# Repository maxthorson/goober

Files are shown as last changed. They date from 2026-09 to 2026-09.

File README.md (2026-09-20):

# Goober

Goober is a compact USB-C macro pad project with two connected halves:

- `website/` contains the public Next.js site for presenting the product, linking
  firmware resources, and experimenting with a hosted QMK configurator surface.
- `hardware/` contains the Rev A hardware package: KiCad PCB files, case models,
  QMK firmware, fabrication docs, mockups, validation notes, and release
  deliverables.

The hardware target is a 9-key RP2040-Zero macro pad with MX hot-swap switches,
an OLED display, a volume/mute knob, and individually addressable RGB lighting.
USB hub and charging passthrough are deferred.

## Project Status

Rev A.1 is a checked engineering prototype ready for a first fabrication and fit
test. It has not yet been built or electrically tested on physical hardware.

The hardware package passes schematic ERC, PCB DRC, and KiCad schematic/PCB
parity checks with zero issues. Firmware compiles, and the printable case
components validate as watertight single-body meshes.

## Repository Layout

| Folder | Purpose |
|---|---|
| `website/` | Next.js product site and QMK configurator integration |
| `hardware/case/` | OpenSCAD source and printable STL case files |
| `hardware/docs/` | Design, fabrication, assembly, firmware, and validation guides |
| `hardware/firmware/` | QMK board files, keymap, build script, and UF2 output |
| `hardware/hardware/` | KiCad schematic, PCB, Gerbers, BOM, and part references |
| `hardware/mockups/` | CAD renders, board images, and appearance concepts |
| `hardware/releases/` | Packaged Rev A prototype release archive |
| `hardware/tools/` | Project-owned helper scripts; large external tools are excluded |

## Start Here

For the site:

```bash
cd website
npm install
npm run dev
```

For the hardware:

1. Read `hardware/docs/DESIGN_PLAN.md` and
   `hardware/docs/PARTS_AND_COST.md`.
2. Use `hardware/docs/FABRICATION.md` to order a small PCB batch.
3. Print the fit coupon, then follow `hardware/docs/ASSEMBLY_AND_TEST.md`.
4. Flash the supplied UF2 or rebuild from `hardware/firmware/`.

## Notes

Large installed tools, virtual environments, downloaded toolchains, and upstream
source checkouts are intentionally not committed. License and provenance notes
for the hardware package are in `hardware/NOTICE.md`.

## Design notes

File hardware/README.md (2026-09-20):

# goober

A compact 9-key USB-C macro pad with MX hot-swap switches, an OLED, a volume/mute knob and individually addressable RGB lighting. RP2040-Zero + QMK. **USB hub and charging passthrough are deferred.**

**Rev A.1 is a checked engineering prototype, ready for a first fabrication and fit test. It has not yet been built or electrically tested on hardware.**

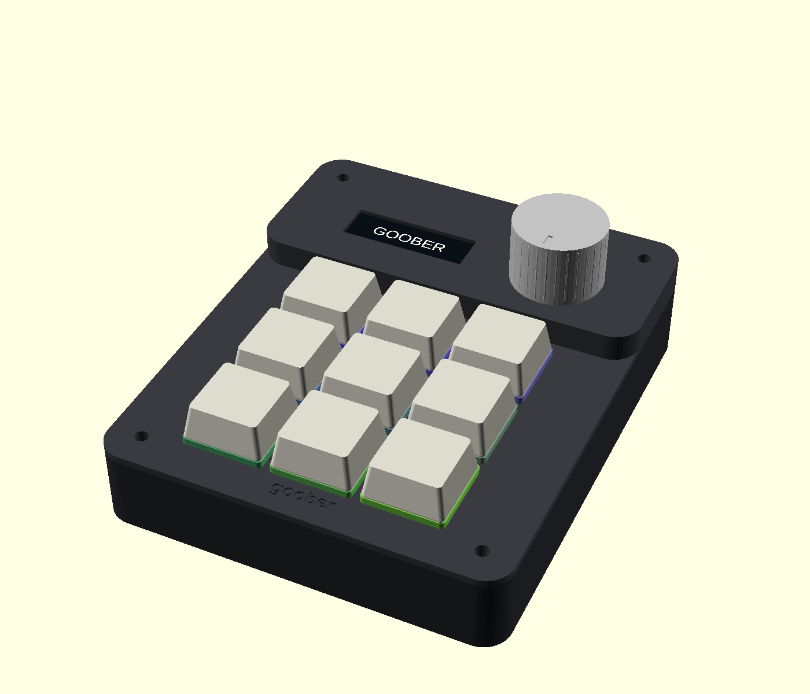
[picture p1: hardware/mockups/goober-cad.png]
Goober mechanical design


## Start here

1. Read [the design plan](docs/DESIGN_PLAN.md) and [parts/cost list](docs/PARTS_AND_COST.md).
2. Use [the fabrication guide](docs/FABRICATION.md) to order a small PCB batch.
3. Print the fit coupon, then follow [assembly and testing](docs/ASSEMBLY_AND_TEST.md).
4. Flash the supplied UF2. [Software and firmware instructions](docs/SOFTWARE_AND_FIRMWARE.md) explain editing and rebuilding.

KiCad, OpenSCAD and the firmware build tools are already installed on this Mac. You only need an optional printer slicer if printing at home. Your remaining work is choosing switches/keycaps, buying parts, printing or ordering the enclosure, soldering and testing the physical prototype.

## Files

| Deliverable | Location |
|---|---|
| Bare-board manufacturing ZIP | [Goober-Rev-A-Gerbers.zip](hardware/Goober-Rev-A-Gerbers.zip) |
| Editable PCB/schematic | [KiCad project](hardware/goober.kicad_pro) — keep adjacent files/libraries together |
| Printable case | [Base](case/goober-base.stl), [lid](case/goober-lid.stl), [knob](case/goober-knob.stl), [fit coupon](case/goober-fit-coupon.stl) |
| Editable case | [OpenSCAD source](case/goober.scad) |
| Ready-to-flash firmware | [Goober UF2](firmware/build/goober-rev-a-default.uf2) |
| Firmware source | [Default keymap](firmware/goober/rev_a/keymaps/default/keymap.c), plus board files in `firmware/goober/rev_a/` |
| Mockups | [Actual CAD](mockups/goober-cad.png), [exploded CAD](mockups/goober-exploded.png), [appearance concept](mockups/goober-appearance.png) |
| Parts list | [Guide](docs/PARTS_AND_COST.md), [CSV](hardware/BOM.csv) |
| Checks and remaining tests | [Validation record](docs/VALIDATION.md) |

The design passes schematic ERC, PCB DRC and KiCad schematic/PCB parity with zero issues. Firmware compiles; the base, lid and knob are watertight single-body meshes. The release includes the detailed validation results and checksums.

The archive in `releases/` contains the deliverables and editable project, without the large installed tools and upstream source checkouts. License/provenance notes are in [NOTICE.md](NOTICE.md).

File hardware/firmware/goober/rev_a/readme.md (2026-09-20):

# Goober revision A

Personal RP2040-Zero macro pad. See the project assembly guide for the hardware pin contract.

Build: `qmk compile -kb goober/rev_a -km default`

Bootloader: hold the module BOOT button while connecting USB, or hold the top-left key while connecting USB (Bootmagic). Copy the UF2 onto RPI-RP2. The USB VID/PID are development identifiers, not an assigned production USB identity.

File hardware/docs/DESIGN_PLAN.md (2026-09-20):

# Goober — revision A design plan

Status: revision A.1 digital design completed; physical prototype testing pending. USB hub/passthrough is deferred at the owner's request. One USB-C device connection remains.

## Product

- Nine MX mechanical switches in a 3×3 grid at 19.05 mm pitch.
- Kailh CPG151101S11 hot-swap sockets. Both 3-pin and 5-pin MX switches; select an RGB-compatible translucent switch housing.
- One reverse-mount SK6812MINI-E RGB LED per key, with a 5 V logic buffer and a switched lighting supply.
- One 128×32 SSD1306 I²C OLED. Shows layer, lighting state and last action.
- One detented encoder with push switch: clockwise volume up, counterclockwise volume down, press mute.
- Waveshare RP2040-Zero module: RP2040, flash, oscillator, USB-C and regulator on a small replaceable assembly.
- QMK firmware, editable source, compiled UF2, no Mac application required for normal operation.
- Two-layer FR-4 carrier PCB, 1.6 mm nominal, with printable case and removable top/plate.

The screen will report volume commands rather than an invented Mac volume percentage. Standard keyboard media reports do not return the host's actual volume.

## Design sequence and acceptance checks

1. Freeze component references and electrical pin assignments.
2. Create the schematic, PCB footprints, routing and BOM. Check the controller header orientation and every LED's power/data pinout against source drawings.
3. Run schematic electrical checks and PCB design-rule checks. Resolve shorts, open connections, copper clearance and outline errors.
4. Export copper, mask, silkscreen, outline and plated/non-plated drill files; inspect the exported geometry.
5. Build the enclosure around the same switch centers, PCB holes, controller port and encoder coordinates. Keep the switch plate thickness and height consistent with MX switch seating.
6. Compile the QMK target with the pinned source revision. Include default macros, lighting controls, display, encoder and bootloader access.
7. Deliver editable sources, prototype fabrication exports, printable geometry, mockups, parts list and assembly/test instructions.
8. Build and physically test a prototype before considering the design production validated.

## Power

USB-powered, with a 500 mA descriptor budget. Lighting brightness is capped in firmware. The LED rail is enabled only after USB configuration and is switched off during suspend. Brightness limiting is a design budget, not a measured current certification. Check startup, steady-state and suspend current on hardware.

The RP2040 GPIOs use 3.3 V logic. The OLED uses 3.3 V and pull-ups to 3.3 V. Addressable LEDs use 5 V; a TTL-input buffer translates their data signal. No accessory charging output, battery, USB 3 hub or laptop charging circuitry is in revision A.

## User's physical tasks

1. Choose nine compatible switches, keycaps and the enclosure color. Default concept: graphite case, light keycaps, silver knob.
2. Order the exact electronics from the BOM and a small batch of prototype boards after reviewing the delivered validation notes.
3. Order or print the case; print the fit coupon first if using an FDM printer.
4. Solder the permanent components, inspect joints, and check for shorts before connecting the controller.
5. Flash the supplied UF2 through the RP2040 bootloader.
6. Fit the plate, insert the hot-swap switches while supporting the sockets, and assemble the enclosure.
7. Run the supplied functional and power checks. Record any fit or electrical corrections for revision B.

## Software on the Mac

- KiCad: PCB/schematic editing, Gerber viewing, DRC and fabrication exports. https://www.kicad.org/download/macos/
- OpenSCAD: parametric case editing and STL export. https://openscad.org/downloads.html
- QMK CLI and Arm compiler: firmware builds. https://docs.qmk.fm/newbs_getting_started
- Printer-specific slicer only if printing at home. A print service can accept STL files directly.
- Homebrew, Git, Python and VS Code were already present.

Project-local firmware dependencies are installed under `tools/`. KiCad and OpenSCAD are installed under the user's Applications directory. QMK Toolbox and Arduino IDE are not required for UF2 drag-and-drop flashing.

## Sources

- RP2040 module and schematic: https://www.waveshare.com/wiki/RP2040-Zero
- OLED dimensions/interface: https://www.waveshare.com/product/ai/0.91inch-oled-module.htm
- QMK processor support: https://docs.qmk.fm/platformdev_rp2040
- QMK lighting: https://docs.qmk.fm/features/rgb_matrix
- QMK encoder: https://docs.qmk.fm/features/encoders
- QMK OLED: https://docs.qmk.fm/features/oled_driver
- Hot-swap socket: https://www.kailhswitch.com/info/kailh-switch-pcb-hot-swapping-socket-33463528.html
- Keyboard footprints: https://github.com/ebastler/marbastlib

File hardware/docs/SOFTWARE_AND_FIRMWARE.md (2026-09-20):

# Mac software and firmware

The design tools have already been installed for this project. **You do not need additional software to flash the supplied firmware.** Finder can copy the UF2 to the RP2040 bootloader drive.

| Tool | Location on this Mac | When you need it |
|---|---|---|
| KiCad 10.0.5 | `/Users/maxthorson/Applications/KiCad/KiCad.app` | Open the PCB project, inspect Gerbers or make electrical changes |
| OpenSCAD 2026.08.27 | `/Users/maxthorson/Applications/OpenSCAD.app` | Open `case/goober.scad`, change dimensions and export STL parts |
| QMK CLI 1.2.0 | `Goober/tools/venv` | Rebuild firmware after editing macros or lighting |
| Arm GNU toolchain 13.3.Rel1 | `Goober/tools/arm-gnu-toolchain-13.3.rel1-darwin-arm64-arm-none-eabi` | Compiler used by the build script |
| Git / Python / Homebrew / VS Code | Already present | Optional code editing and dependency management |
| Printer-specific slicer | Not installed by this project | Only needed if you print at home; a print service takes STL files |

QMK Toolbox, Arduino IDE and Raspberry Pi OS are not needed for this design. Official download pages for another machine are in `DESIGN_PLAN.md`. On a different machine, follow QMK's setup guide for the CLI/compiler; the firmware build script uses system-installed tools if project-local copies are absent. OpenSCAD's installed version is a development snapshot; the generated STL files can be used without it.

## Flash the supplied binary

Hold the RP2040-Zero's BOOT button while connecting its USB-C data cable. In Finder, copy `firmware/build/goober-rev-a-default.uf2` to **RPI-RP2**. The drive disappears when flashing finishes and the module reboots. No flashing tool, account or API key is required.

The compiled image has an 86,016-byte UF2 container and a 43,008-byte flash payload. The exact SHA-256 is recorded in `validation/firmware.json` and the release checksums. It is built for RP2040, not RP2350/Pico 2.

## Edit and rebuild

The source you normally edit is `firmware/goober/rev_a/keymaps/default/keymap.c`. Key order is top-left to bottom-right, followed by the encoder's push switch. `COPY`, `PASTE`, `UNDO` and `SHOT` are Mac shortcuts; replace those with the shortcuts you want. F13 and F14 are available for app assignments.

From Terminal:

```sh
cd /Users/maxthorson/Goober
./firmware/build.sh
```

The script copies the editable keyboard files into the local QMK checkout, builds them and refreshes `firmware/build/goober-rev-a-default.uf2`. It expects upstream QMK revision `e6a31e474a931060412bb72c4c48131f58ac4bbc`. On a fresh copy, it downloads that checkout and its required submodules. It refuses to silently change an existing checkout at a different revision. Reflash the new UF2 after a successful build.

The local upstream source lives in `tools/qmk_firmware`. The delivery ZIP contains the complete Goober-specific firmware sources and a pinned build script; the large installed tools/checkouts are kept separately on this Mac. QMK's source and dependency licenses remain in its checkout, and license notices are also included with this project.

## Controls and display

The shipped key layout is:

| | Left | Middle | Right |
|---|---|---|---|
| Top | Copy | Paste | Undo |
| Middle | Previous track | Play/pause | Next track |
| Bottom | Screenshot selection | F13 | Tap F14 / hold LIGHTS |

Turn the knob for volume; press it for mute. Hold bottom-right to change the knob to brightness. On the LIGHTS layer, top-left toggles RGB, top-middle/right changes effects, middle-left/bottom-left changes hue, middle-middle/bottom-middle changes saturation, and middle-right raises brightness. Lighting settings use QMK's persistent settings. There is no separate configuration app in this version.

The OLED reports the current layer, lighting enable/brightness and last command. It is monochrome, 128 × 32 pixels. It does not receive the Mac's actual volume percentage. QMK effects drive the nine LEDs individually; reactive effects use the matching switch positions.

For custom per-key colors, use QMK's `rgb_matrix_indicators_user` hook and `rgb_matrix_set_color(index, r, g, b)` in the keymap. LED indices 0–8 follow reading order. If adding a custom hook, explicitly honor the chosen brightness cap and RGB enable state—direct color writes can bypass a theme's normal brightness scaling. The included default uses the standard QMK effects and controls.

## Hardware pin map

| RP2040 GPIO | Function |
|---|---|
| GP0–GP8 | Nine switches, each closes directly to ground |
| GP9 | LED power enable, active high |
| GP10 / GP11 | Encoder A / B |
| GP12 | Encoder press, closes to ground |
| GP13 | RGB data through the 5 V AHCT buffer |
| GP14 / GP15 | OLED SDA / SCL, 3.3 V I²C |

RGB brightness is capped at 64/255, default 32. The switched LED rail is off before USB configuration and while suspended. The buffer is disabled when the lighting rail is off. GPIO16's LED on the controller module is not used by this keyboard.

The USB VID/PID (`FEED:0901`) are development placeholders, not an assigned commercial USB identity. Hardware testing and a suitable USB identity remain necessary before turning this into a distributed product.

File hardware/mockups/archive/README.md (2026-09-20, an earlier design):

This early concept predates the decision to defer the hub/charging passthrough. It is historical only and is excluded from the release ZIP. The current design uses exactly one USB-C port. Use ../goober-appearance.png and ../goober-cad.png for the current revision.

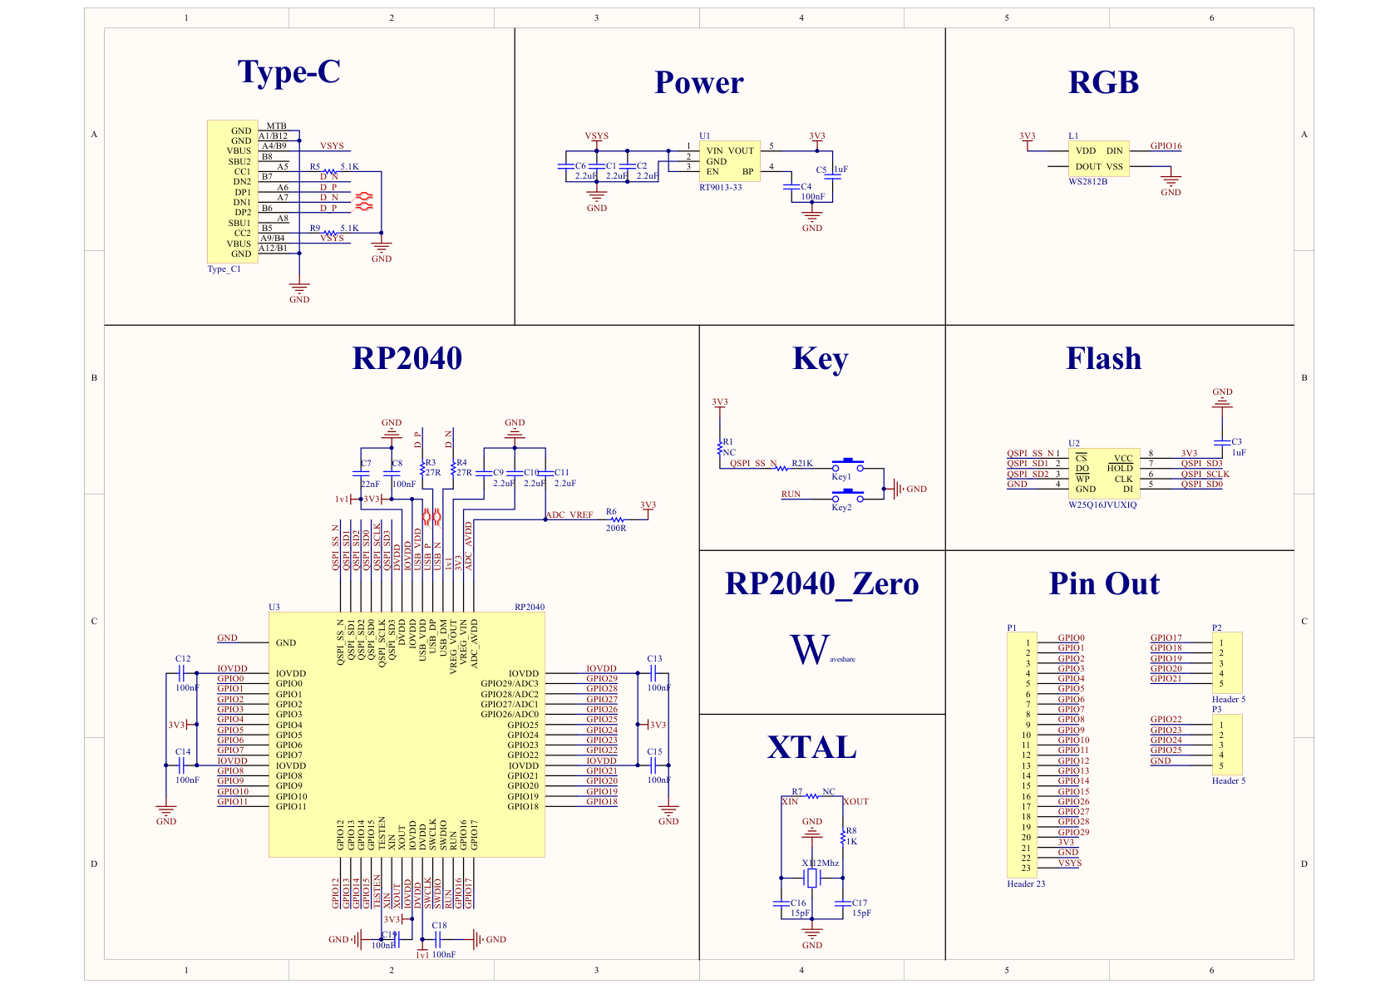
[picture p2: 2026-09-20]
hardware/validation/rp2040-pinout.png

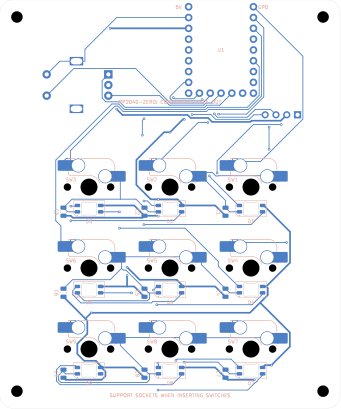
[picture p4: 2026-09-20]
hardware/mockups/pcb-bottom.png

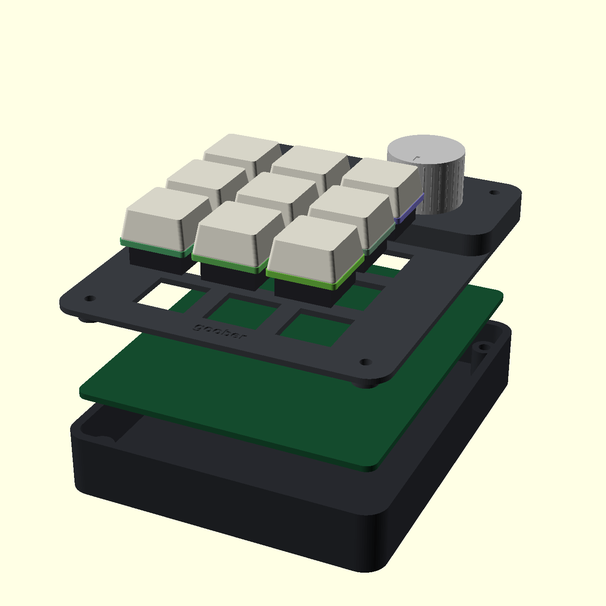
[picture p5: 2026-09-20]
hardware/mockups/goober-exploded.png

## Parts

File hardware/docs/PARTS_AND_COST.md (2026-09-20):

# Parts and cost — Goober Rev A

This is the purchasing list for one prototype. Budget roughly **US$50–100 plus shipping and tax** for a small PCB order, parts and a basic print if you already have soldering tools. This is a planning allowance, not a live supplier quote. Small-order shipping and switch/keycap choices can dominate the total. A soldering service or purchased tools add cost.

Buy spare LEDs, sockets and small components; quantities below are what one board uses. The design intentionally uses a ready-made USB-C controller and two PCB layers to keep the first build manageable. There is no hub or charging passthrough in this revision.

| Ref | Qty | Buy this | Package / selection detail |
|---|---:|---|---|
| PCB | 1 | Goober Rev A.1 carrier | 80 × 96 mm, 2 layers, 1.6 mm FR-4; Gerber ZIP supplied |
| U1 | 1 | Waveshare **RP2040-Zero** | USB-C, 18 × 23.5 mm; get the unpopulated-header version so mounting height can be set |
| SW1–SW9 | 9 | Kailh **CPG151101S11** MX hot-swap sockets | Original MX style; Choc/low-profile sockets do not fit |
| D1–D9 | 9 | OPSCO **SK6812MINI-E-012** | Reverse mount, 3.2 × 2.8 mm, 12 mA/channel version; order 12–15. LCSC C5149201 is the source used for the datasheet |
| ENC1 | 1 | Alps Alpine **EC11E15244G1** | Push switch, 30 detents/15 pulses, 20 mm actuator. A generic EC11 may have a different height or pulse count |
| OLED | 1 | Waveshare **0.91inch OLED Module**, SKU 14657 | SSD1306, I²C, 128 × 32, monochrome white, 36 × 12.5 mm board; 3.3 V operation |
| U2 | 1 | Texas Instruments **SN74AHCT125D** or **SN74AHCT125DR** | SOIC-14, 3.9 mm body / 1.27 mm pitch. The D/DR package matters; do not substitute HC or AHC |
| Q1 | 1 | Alpha & Omega **AO3401A** | P-channel MOSFET, SOT-23, pin 1 gate / 2 source / 3 drain |
| Q2 | 1 | onsemi **MMBT3904LT1G** | NPN, SOT-23, pin 1 base / 2 emitter / 3 collector |
| F1 | 1 | Littelfuse **1206L050YR** | 0.5 A hold resettable PTC, 1206 footprint |
| C1–C10 | 10 | 100 nF ceramic, 16 V or higher, X7R | 0805 imperial / 2012 metric. C1–C9 on bottom; C10 on top |
| C11 | 1 | 4.7 µF ceramic, 16 V, X5R or X7R | 0805 imperial / 2012 metric |
| R1, R3 | 2 | 100 kΩ, 1%, ≥0.125 W | 0805 imperial / 2012 metric |
| R2 | 1 | 10 kΩ, 1%, ≥0.125 W | 0805 |
| R4 | 1 | 330 Ω, 1%, ≥0.125 W | 0805 |
| R5, R6, R9 | 3 | 4.7 kΩ, 1%, ≥0.125 W | 0805 |
| R7, R8 | 2 | 3.3 kΩ, 1%, ≥0.125 W | 0805 |
| J1 wiring | 1 set | Four flexible insulated wires, 28–30 AWG, about 50 mm each | Solder directly into J1 pads; **do not install a tall pin header under the OLED cradle**. Use the OLED's included harness or its labeled solder holes |
| U1 interconnect | 23 pins | 2.54 mm pitch, 0.64 mm square breakaway pin strips | Cut into 2 × 9-pin and 1 × 5-pin strips; enough pin length for both boards plus a **3.0 mm gap**. Soldered module; not a plug-in socket |
| Switches | 9 | MX-compatible, standard-height, 3-pin or 5-pin | Choose translucent/RGB-compatible housing and your preferred feel. The switch must suit a 1.5 mm plate |
| Keycaps | 9 | 1u MX-stem keycaps | Uniform profile is simplest; shine-through or translucent sides show more light |
| Case | 1 set | Printed base + lid | STL and editable OpenSCAD source included |
| Knob | 1 | Printed Goober knob | 6 mm D-shaft fit. The supplied knob is 20 mm diameter × 14 mm tall |
| Inserts | 4 | M2.5 brass heat-set inserts | Nominal OD 3.8 mm × 4.0 mm long; test the coupon with the actual brand |
| Front screws | 2 | M2.5 × 12 mm machine screws | Pan/button head, not countersunk; front is the key side |
| Rear screws | 2 | M2.5 × 18 mm machine screws | Pan/button head; rear is the OLED/encoder side |
| Feet | 4 | 8 mm adhesive rubber feet | Thickness ≥1 mm; recess is 0.6 mm deep |
| OLED attachment | small amount | Thin electronics-safe double-sided tape | Only under PCB edges on the cradle ledges; do not press or tape the display glass |
| Cable | 1 | USB-C data cable to suit the Mac | Charging-only cables cannot send keys; plug body should fit the 14 × 8 mm rear opening |

The hot-swap feature applies to the **nine switches**. The sockets, LEDs, encoder, controller and other electronics are soldered permanently in this low-cost prototype.

## Tools you need physically

Temperature-controlled fine-tip soldering iron, solder, flux, fine tweezers, solder wick, magnification, flush cutters, multimeter, calipers, a small screwdriver and a switch puller. Use ventilation for soldering. Heat-set inserts need a suitable iron tip. A USB current meter is useful for testing; a current-limited 5 V supply or current-limited USB test adapter helps with first power-up. A PCB assembly service can handle the small surface-mount parts if you prefer.

Use your own printer and its slicer, or send the STLs to a print service. You do not need to buy a printer.

## Source pages used for component selection

- [Waveshare RP2040-Zero](https://www.waveshare.com/wiki/RP2040-Zero)
- [Waveshare OLED](https://www.waveshare.com/product/ai/0.91inch-oled-module.htm)
- [Alps encoder specification](https://tech.alpsalpine.com/e/products/detail/EC11E15244G1/)
- [TI buffer](https://www.ti.com/product/SN74AHCT125)
- [AO3401A datasheet](https://www.aosmd.com/pdfs/datasheet/AO3401A.pdf)
- [onsemi transistor datasheet](https://www.onsemi.com/pdf/datasheet/mmbt3904lt1-d.pdf)
- [SK6812MINI-E-012 datasheet](../hardware/sk6812mini-e.pdf)

Check the exact part and package at checkout. A listing that only says “Pico,” “0.91 OLED,” “EC11” or “SK6812” does not establish compatibility with these files.

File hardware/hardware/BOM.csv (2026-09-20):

Reference | Quantity | Description | Manufacturer part or selection | Footprint | Side | Notes
U1 | 1 | Waveshare RP2040-Zero | Waveshare RP2040-Zero | RP2040_Zero_Headers | B | Bottom; components outward/down; 3.0 mm board-to-module-back gap; needs 23 header pins
SW1 | 1 | Kailh CPG151101S11 | CPG151101S11 | SW_MX_HS_CPG151101S11_1u | B | Socket only; purchase actual MX switches separately
D1 | 1 | SK6812MINI-E | SK6812MINI-E-012 | LED_SK6812MINI-E_3.2x2.8mm_P1.5mm_ReverseMount | B | Reverse mount through window; pin1 GND,2 DIN,3 VDD,4 DOUT
C1 | 1 | 100nF 16V X7R |  | C_0805_2012Metric | B
SW2 | 1 | Kailh CPG151101S11 | CPG151101S11 | SW_MX_HS_CPG151101S11_1u | B | Socket only; purchase actual MX switches separately
D2 | 1 | SK6812MINI-E | SK6812MINI-E-012 | LED_SK6812MINI-E_3.2x2.8mm_P1.5mm_ReverseMount | B | Reverse mount through window; pin1 GND,2 DIN,3 VDD,4 DOUT
C2 | 1 | 100nF 16V X7R |  | C_0805_2012Metric | B
SW3 | 1 | Kailh CPG151101S11 | CPG151101S11 | SW_MX_HS_CPG151101S11_1u | B | Socket only; purchase actual MX switches separately
D3 | 1 | SK6812MINI-E | SK6812MINI-E-012 | LED_SK6812MINI-E_3.2x2.8mm_P1.5mm_ReverseMount | B | Reverse mount through window; pin1 GND,2 DIN,3 VDD,4 DOUT
C3 | 1 | 100nF 16V X7R |  | C_0805_2012Metric | B
SW4 | 1 | Kailh CPG151101S11 | CPG151101S11 | SW_MX_HS_CPG151101S11_1u | B | Socket only; purchase actual MX switches separately
D4 | 1 | SK6812MINI-E | SK6812MINI-E-012 | LED_SK6812MINI-E_3.2x2.8mm_P1.5mm_ReverseMount | B | Reverse mount through window; pin1 GND,2 DIN,3 VDD,4 DOUT
C4 | 1 | 100nF 16V X7R |  | C_0805_2012Metric | B
SW5 | 1 | Kailh CPG151101S11 | CPG151101S11 | SW_MX_HS_CPG151101S11_1u | B | Socket only; purchase actual MX switches separately
D5 | 1 | SK6812MINI-E | SK6812MINI-E-012 | LED_SK6812MINI-E_3.2x2.8mm_P1.5mm_ReverseMount | B | Reverse mount through window; pin1 GND,2 DIN,3 VDD,4 DOUT
C5 | 1 | 100nF 16V X7R |  | C_0805_2012Metric | B
SW6 | 1 | Kailh CPG151101S11 | CPG151101S11 | SW_MX_HS_CPG151101S11_1u | B | Socket only; purchase actual MX switches separately
D6 | 1 | SK6812MINI-E | SK6812MINI-E-012 | LED_SK6812MINI-E_3.2x2.8mm_P1.5mm_ReverseMount | B | Reverse mount through window; pin1 GND,2 DIN,3 VDD,4 DOUT
C6 | 1 | 100nF 16V X7R |  | C_0805_2012Metric | B
SW7 | 1 | Kailh CPG151101S11 | CPG151101S11 | SW_MX_HS_CPG151101S11_1u | B | Socket only; purchase actual MX switches separately
D7 | 1 | SK6812MINI-E | SK6812MINI-E-012 | LED_SK6812MINI-E_3.2x2.8mm_P1.5mm_ReverseMount | B | Reverse mount through window; pin1 GND,2 DIN,3 VDD,4 DOUT
C7 | 1 | 100nF 16V X7R |  | C_0805_2012Metric | B
SW8 | 1 | Kailh CPG151101S11 | CPG151101S11 | SW_MX_HS_CPG151101S11_1u | B | Socket only; purchase actual MX switches separately
D8 | 1 | SK6812MINI-E | SK6812MINI-E-012 | LED_SK6812MINI-E_3.2x2.8mm_P1.5mm_ReverseMount | B | Reverse mount through window; pin1 GND,2 DIN,3 VDD,4 DOUT
C8 | 1 | 100nF 16V X7R |  | C_0805_2012Metric | B
SW9 | 1 | Kailh CPG151101S11 | CPG151101S11 | SW_MX_HS_CPG151101S11_1u | B | Socket only; purchase actual MX switches separately
D9 | 1 | SK6812MINI-E | SK6812MINI-E-012 | LED_SK6812MINI-E_3.2x2.8mm_P1.5mm_ReverseMount | B | Reverse mount through window; pin1 GND,2 DIN,3 VDD,4 DOUT
C9 | 1 | 100nF 16V X7R |  | C_0805_2012Metric | B
ENC1 | 1 | ALPS EC11E15244G1 | EC11E15244G1 | RotaryEncoder_Alps_EC11E-Switch_Vertical_H20mm | F
J1 | 1 | OLED: GND 3V3 SCL SDA | Direct soldered 4-wire harness | PinHeader_1x04_P2.54mm_Vertical | F | No tall header; wire OLED by signal names GND/VCC/SCL/SDA
U2 | 1 | SN74AHCT125D | SN74AHCT125DR | SOIC-14_3.9x8.7mm_P1.27mm | F
Q1 | 1 | AO3401A P-MOSFET | AO3401A | SOT-23 | F
Q2 | 1 | MMBT3904 NPN | MMBT3904LT1G | SOT-23 | F
R1 | 1 | 100k |  | R_0805_2012Metric | F
R2 | 1 | 10k |  | R_0805_2012Metric | F
R3 | 1 | 100k |  | R_0805_2012Metric | F
R4 | 1 | 330R |  | R_0805_2012Metric | F
R5 | 1 | 4.7k |  | R_0805_2012Metric | F
R6 | 1 | 4.7k |  | R_0805_2012Metric | F
R7 | 1 | 3.3k |  | R_0805_2012Metric | F
R8 | 1 | 3.3k |  | R_0805_2012Metric | F
R9 | 1 | 4.7k |  | R_0805_2012Metric | F
C10 | 1 | 100nF 16V X7R |  | C_0805_2012Metric | F
C11 | 1 | 4.7uF 16V X5R |  | C_0805_2012Metric | F
F1 | 1 | 1206L050YR 0.5A PTC | 1206L050YR | Fuse_1206_3216Metric | F
OLED | 1 | 128x32 monochrome OLED | Waveshare 0.91inch OLED Module SKU14657 |  | Off-board | 36x12.5mm; 3.3V I2C
SWITCHES | 9 | Standard-height RGB-compatible MX switches | User choice |  | Off-board | 3-pin or5-pin; 1.5mm plate
KEYCAPS | 9 | 1u MX-stem keycaps | User choice |  | Off-board | Uniform profile suggested
U1_PINS | 23 | 2.54mm pitch 0.64mm square header pins | Breakaway 2x9 +1x5 |  | Off-board | 3.0mm gap between boards
INSERTS | 4 | M2.5 brass heat-set inserts | OD3.8 x L4.0mm |  | Off-board | Test coupon first
SCREWS_FRONT | 2 | M2.5 x12mm machine screw | Pan/button head |  | Off-board | Front key side
SCREWS_REAR | 2 | M2.5 x18mm machine screw | Pan/button head |  | Off-board | Rear hood side
FEET | 4 | 8mm adhesive rubber feet | User choice |  | Off-board | Thickness >=1mm
CASE_BASE | 1 | Printed base | goober-base.stl |  | Off-board | Millimetres; 100%
CASE_LID | 1 | Printed lid | goober-lid.stl |  | Off-board | Print with appropriate supports
KNOB | 1 | Printed 6mm D-shaft knob | goober-knob.stl |  | Off-board | Fit test actual shaft
USB_CABLE | 1 | USB-C data cable | Match Mac port |  | Off-board | Plug overmold fits14x8mm opening
OLED_TAPE | 1 | Thin double-sided electronics tape | Small amount |  | Off-board | PCB ledges only, not glass

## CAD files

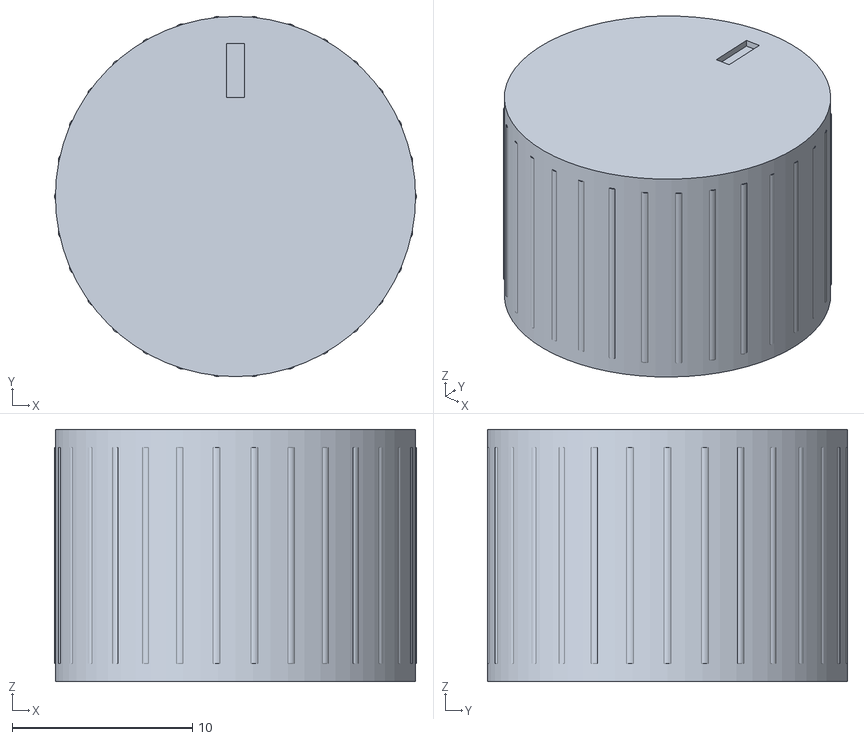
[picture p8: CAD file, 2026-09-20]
hardware/case/goober-knob.stl
20.1 x 20.0 x 14.0

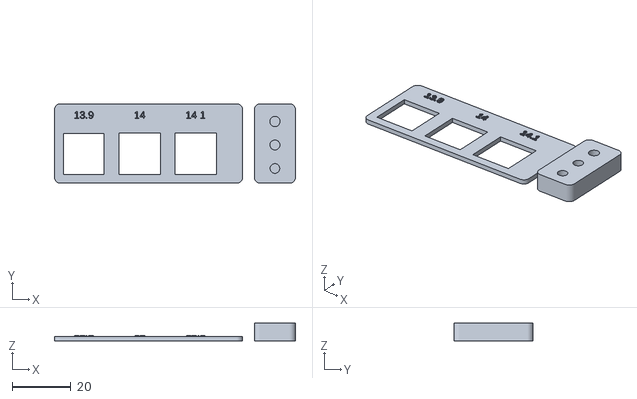
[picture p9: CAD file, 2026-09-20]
hardware/case/goober-fit-coupon.stl
82.0 x 27.0 x 6.00

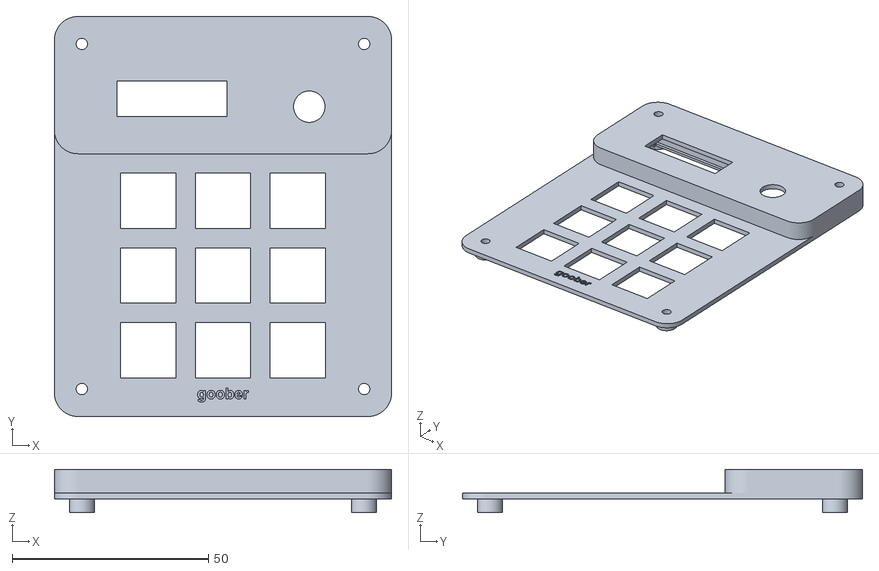
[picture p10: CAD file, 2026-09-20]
hardware/case/goober-lid.stl
86.0 x 102.0 x 11.0

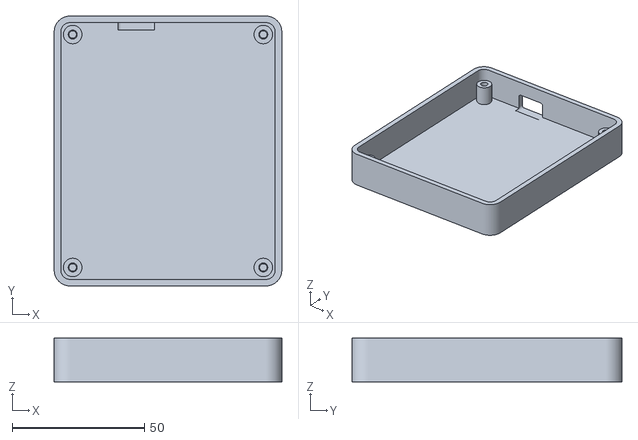
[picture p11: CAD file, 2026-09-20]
hardware/case/goober-base.stl
86.0 x 102.0 x 16.5

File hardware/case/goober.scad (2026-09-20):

// Goober Rev A — millimetres. Engineering prototype; print fit coupon first.
// Parts: "base", "lid", "knob", "coupon", "assembly", "exploded".
part = "assembly";
$fn = 64;
pcb_w=80; pcb_h=96; pcb_t=1.6;
pcb_top=13; pcb_bottom=pcb_top-pcb_t;
plate_t=1.5; plate_top=18; plate_bottom=plate_top-plate_t;
hood_top=24; hood_front=32;
wall=2.5; floor_t=2.4; gap=.5;
switch_cut=14.10;
insert_hole=3.4; // Nominal for M2.5 insert, OD 3.8, length 4.0; test coupon.
holes=[[4,4],[76,4],[4,92],[76,92]];
keys=[for(r=[0:2],c=[0:2]) [40+(c-1)*19.05,44+r*19.05]];
oled=[27,18]; encoder=[62,20];

module rounded(w,h,r,z) {
    linear_extrude(z) hull() for(x=[r,w-r],y=[r,h-r]) translate([x,y]) circle(r=r);
}
module outside(h) {translate([-3,-3,0]) rounded(86,102,6,h);}
module inside(h) {translate([-.5,-.5,0]) rounded(81,97,3.5,h);}
module usb_cut() {
    // Large enough for plug overmould to reach the recessed module connector.
    translate([28,-1.75,5.8]) rotate([90,0,0])
        linear_extrude(8,center=true) hull()
            for(x=[-5.8,5.8],y=[-2.8,2.8]) translate([x,y]) circle(r=1.2);
}
module base() {
    difference() {
        union() {
            difference() {
                outside(plate_bottom);
                translate([0,0,floor_t]) inside(30);
            }
            for(p=holes) translate([p[0],p[1],floor_t]) cylinder(d=7,h=pcb_bottom-floor_t);
        }
        usb_cut();
        for(p=holes) {
            translate([p[0],p[1],floor_t+.5]) cylinder(d=2.8,h=20);
            translate([p[0],p[1],pcb_bottom-4.1]) cylinder(d=insert_hole,h=4.3);
        }
        // Feet recesses: adhesive 8-mm rubber feet, 0.6 mm deep.
        for(p=[[8,8],[72,8],[8,88],[72,88]]) translate([p[0],p[1],-.1]) cylinder(d=8.3,h=.7);
    }
}
module hood_outer() {translate([-3,-3,plate_top-.01]) rounded(86,hood_front+3,6,hood_top-plate_top+.01);}
module lid() {
    difference() {
        union() {
            difference() {
                union() {
                    translate([0,0,plate_bottom]) outside(plate_t);
                    hood_outer();
                }
                // Hollow control area, leaving a 1.5-mm roof and 2.5-mm walls.
                translate([-.5,-.5,plate_bottom-.1]) rounded(81,hood_front-2,3.5,hood_top-plate_t-plate_bottom+.1);
                for(p=keys) translate([p[0]-switch_cut/2,p[1]-switch_cut/2,plate_bottom-.1]) cube([switch_cut,switch_cut,2]);
                translate([oled[0]-14,oled[1]-4.5,hood_top-2]) cube([28,9,3]);
                translate([encoder[0],encoder[1],hood_top-2]) cylinder(d=8,h=3);
            }
            // Spacers set the MX plate top exactly 5 mm above PCB top.
            for(p=holes) translate([p[0],p[1],pcb_top]) cylinder(d=6.4,h=(p[1]<10?hood_top:plate_top)-pcb_top);
            // OLED pocket suspended below roof; open end for the PH connector.
            difference() {
                translate([oled[0]-20,oled[1]-8.6,18.3]) cube([40,17.2,4.2]);
                translate([oled[0]-18.3,oled[1]-6.55,19.1]) cube([36.6,13.1,5]);
                translate([oled[0]-17.3,oled[1]-5.55,18.2]) cube([34.6,11.1,1]);
                translate([oled[0]-20.1,oled[1]-4.5,18.2]) cube([4,9,3.1]);
                translate([oled[0]-14,oled[1]-4.5,18]) cube([28,9,8]);
            }
        }
        for(p=holes) translate([p[0],p[1],12]) cylinder(d=2.9,h=15);
        // Thin front identification engraving.
        translate([40,93.5,17.6]) linear_extrude(.5) mirror([0,1,0])
            text("goober",size=2.8,halign="center",valign="center",font="Helvetica:style=Bold");
    }
}
module knob() {
    difference() {
        union() {
            cylinder(d=20,h=14);
            for(a=[0:12:348]) rotate([0,0,a]) translate([9.7,0,1]) cylinder(d=.7,h=12);
        }
        // D shaft: 6.2-mm bore, flat 1.65 mm from centre; blind 12-mm depth.
        intersection() {
            translate([0,0,-.1]) cylinder(d=6.2,h=12.1);
            translate([-4,-4,-.1]) cube([5.65,8,12.1]);
        }
        translate([-.5,5.5,13.6]) cube([1,3,.6]);
    }
}
module coupon() {
    difference() {
        rounded(64,27,2,1.5);
        for(i=[0:2]) translate([3+i*19,3,-.1]) cube([13.9+i*.1,13.9+i*.1,2]);
    }
    for(i=[0:2]) translate([10+i*19,22,1.5]) linear_extrude(.35) text(str(13.9+i*.1),size=2.5,halign="center");
    translate([68,0,0]) difference() {
        rounded(14,27,2,6);
        for(i=[0:2]) translate([7,5+i*8,1]) cylinder(d=3.3+i*.1,h=6);
    }
}
module preview_components(explode=0, key_raise=0, control_raise=0) {
    color([.08,.3,.18]) translate([0,0,pcb_bottom+explode]) rounded(pcb_w,pcb_h,3,pcb_t);
    color([.13,.15,.18]) translate([19,0,7.4+explode]) cube([18,23.5,1]);
    color("silver") translate([23.6,-1.2,4.2+explode]) cube([8.8,7.5,3.2]);
    color([.1,.1,.13]) translate([9,11.75,19.1+control_raise]) cube([36,12.5,1.2]);
    color([.03,.06,.08]) translate([13,13.5,22.6+control_raise]) cube([28,9,.5]);
    color("white") translate([27,18,23.2+control_raise]) linear_extrude(.05) mirror([0,1,0]) text("GOOBER",size=2.8,halign="center",valign="center");
    for(i=[0:8]) {
        p=keys[i];
        color([.15,.15,.17]) translate([p[0]-7,p[1]-7,pcb_top+key_raise]) cube([14,14,5]);
        color([.3+.07*(i%3),.3+.06*i,.9-.08*i]) translate([p[0]-8.7,p[1]-8.7,plate_top+.5+key_raise]) rounded(17.4,17.4,1,1.5);
        color([.86,.85,.8]) translate([p[0],p[1],plate_top+2+key_raise]) hull() {
            translate([-8.5,-8.5,0]) rounded(17,17,1,.3);
            translate([-7.3,-7.3,7]) rounded(14.6,14.6,1,.3);
        }
    }
    color("silver") translate([encoder[0],encoder[1],26+control_raise]) knob();
}
module layout() {
if(part=="base") base();
else if(part=="lid") translate([0,0,-pcb_top]) lid();
else if(part=="knob") knob();
else if(part=="coupon") coupon();
else if(part=="exploded") {
    color([.15,.16,.18])base();
    color([.22,.23,.25])translate([0,0,35])lid();
    preview_components(15,50,35);
} else {
    color([.15,.16,.18])base();
    color([.22,.23,.25])lid();
    preview_components();
}

}
// KiCad plan coordinates: +Y runs down the page. Convert to CAD world.
if(part=="coupon" || part=="knob") layout();
else mirror([0,1,0]) layout();

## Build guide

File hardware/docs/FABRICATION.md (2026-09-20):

# PCB fabrication — revision A.1

Upload **`hardware/Goober-Rev-A-Gerbers.zip`** as the bare-board fabrication file. This ZIP contains seven Gerber layers, two Excellon drill files and the KiCad job metadata. It does not order components or assembly.

| Setting | Value |
|---|---|
| Board outline | 80 × 96 mm, rounded corners, radius 3 mm |
| Material / thickness | FR-4, **1.6 mm** |
| Copper layers | **2** |
| Copper weight | 1 oz finished nominal |
| Finish | Lead-free HASL for cost; ENIG optional |
| Solder mask | Both sides; any color |
| Silkscreen | Both sides |
| Minimum copper clearance / signal trace | 0.20 mm / 0.20 mm |
| Smallest plated drill / via land | 0.30 mm / 0.60 mm |
| Minimum copper-to-routed-edge | 0.25 mm |
| Impedance control | Not required; USB data routing is entirely on the bought controller module |
| Castellations / edge plating | None on this carrier |
| Panelization | Single board outline; let the fabricator handle their process panel |

Keep plated and non-plated drill files separate. The switch contact holes are intentionally plated. The center and plastic-leg switch holes, and the four mounting holes, are non-plated. Two encoder mechanical holes are plated routed slots.

**The nine internal LED windows on Edge.Cuts must be milled through the PCB.** They are not printed graphics. Check that the fabricator's upload viewer recognizes one outer contour and nine internal contours; request confirmation of the internal routing if the preview omits it. The cutouts include rounded reliefs. The board also has 31 non-plated drill hits and 90 plated drill/slot objects in the independent export check.

Gerber mapping:

| File | Purpose |
|---|---|
| `goober-F_Cu.gtl` / `goober-B_Cu.gbl` | Top / bottom copper |
| `goober-F_Mask.gts` / `goober-B_Mask.gbs` | Top / bottom solder-mask openings |
| `goober-F_Silkscreen.gto` / `goober-B_Silkscreen.gbo` | Top / bottom printing |
| `goober-Edge_Cuts.gm1` | Outside shape and nine LED openings |
| `goober-PTH.drl` | Plated holes and slots |
| `goober-NPTH.drl` | Non-plated holes |

The exact editable project is `hardware/goober.kicad_pro`, with the adjacent schematic, PCB and local libraries. Keep those files together. The schematic uses labeled component blocks with every pin shown; it is electrically connected and linked to the PCB. Routed power nets use the same named net connectivity as the schematic.

The bottom side carries U1, SW1–SW9, D1–D9 and C1–C9. Other small parts and the encoder are on top. J1 is a low-profile wire connection in the assembly, despite using a standard header footprint. `BOM.csv` is a manual build list, not a pre-approved factory assembly order. Through-hole module installation and OLED wiring need the assembly guide.

The SK6812MINI-E footprint is based on KiCad's reverse-mount footprint. Its SMD lands were reduced from 1.35 to **1.30 mm** in the long dimension to meet the 0.25 mm copper-to-milled-edge clearance. The supplied local library includes this change. Do not replace it with the stock footprint without rechecking clearance.

These are prototype fabrication outputs. Automated rule checks do not verify solderability, real component tolerances, USB compliance, current consumption or the feel of the assembled device. Build and validate one prototype before larger orders.

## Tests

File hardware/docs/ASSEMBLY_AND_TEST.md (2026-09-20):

# Build and test your Goober

The files are an **engineering prototype release**. The schematic and PCB pass automated electrical checks, the firmware compiles, and the case meshes pass digital checks. An assembled board has not yet been powered or physically fitted. Start with one build and use the checks below before ordering a larger batch.

## 1. Review and order

Read `PARTS_AND_COST.md` and `FABRICATION.md`. Upload `hardware/Goober-Rev-A-Gerbers.zip` to a PCB fabricator, select two layers, 1.6 mm FR-4 and 1 oz copper, and check the preview for the outside shape and all nine LED windows. Order the exact controller, encoder, OLED, LEDs and sockets in the parts list. Choose nine switches/keycaps and a case color.

The PCB is 80 × 96 mm. The assembled case is 86 × 102 mm, 18 mm high over the key plate, 24 mm over the control hood, and approximately 40 mm overall with the supplied knob, excluding feet. Keycap height varies with the chosen set.

## 2. Print the fit coupon, then the enclosure

All STLs use **millimetres**. Print at 100% scale. The coupon deliberately contains two separate pieces: a switch plate and an insert block. It tests 13.9, 14.0 and 14.1 mm switch openings in that order, and 3.3, 3.4 and 3.5 mm insert pilots. Use the same printer, material and settings as the case.

The supplied lid uses a 14.1 mm switch opening and a 1.5 mm plate. Check that your switch snaps in, sits flat and can be removed without breaking the clips. Test an insert in the 3.4 mm pilot. Adjust `switch_cut` or `insert_hole` in `case/goober.scad` and re-export if needed; do not scale the entire enclosure, because that moves every mounting hole.

Starting print settings: PLA or PETG, 0.4 mm nozzle, 0.15 mm layers (so the plate is ten layers), four walls and 25–35% infill. Print the base floor-down, knob bore-down, coupon flat. The lid has a raised roof and projecting spacers: orient it with the control roof toward the bed and use supports under the key plate and other overhangs. Inspect the slicer's layer preview and remove supports carefully from switch openings, OLED ledges and screw bores. A print service can choose an equivalent process and orientation.

Install four heat-set inserts into the base bosses from above, ending flush with the boss tops. Let them cool before fitting screws. Do not melt the bosses down or allow an insert to protrude into the PCB seating surface. The actual insert manufacturer's pilot recommendation and the coupon govern fit.

## 3. Solder and inspect the carrier PCB

“Top” is the side the switches and encoder enter. The controller, nine hot-swap sockets, nine LEDs and C1–C9 go on the **bottom**. Use the PCB drawings and reference labels to locate parts; the bottom drawing is mirrored as viewed from below.

1. Solder the small top-side parts first: R1–R9, C10–C11, F1, Q1, Q2 and U2. Check values and orientation. R and C parts are non-polarized. U2's pin-1 mark must match pin 1 in KiCad; Q1 and Q2 are different parts despite sharing a package.
2. Solder C1–C9 and reverse-mount LEDs on the bottom. Each LED's emitting body goes into its milled PCB window and shines upward toward the switch. **LED pin 1 is GND, pin 2 is data in, pin 3 is +5 V, pin 4 is data out.** Compare the physical package marking and datasheet with the numbered pads in KiCad; do not guess orientation from the word “LED.” D9's data-out pad is intentionally unconnected.
3. Solder all nine hot-swap sockets on the bottom, flush to the PCB. Their plastic bodies and contacts must align with the corresponding switch holes. Do not fill the switch contact holes with solder.
4. Solder the encoder on top, fully seated, including both mechanical tabs. It needs the exact shaft height in the BOM.
5. Solder four flexible wires directly into J1. Keep wire exits low and route the harness away from the switch holes and screw bosses. Leave about 50 mm to connect the OLED under the removable lid. A tall vertical header and Dupont plugs would interfere with the cradle.
6. Inspect every joint for bridges or loose solder. With power disconnected, check resistance between USB 5 V and ground, 3.3 V and ground, and the switched LED rail and ground. Capacitors can cause a brief changing reading; a persistent near-zero reading must be investigated. Compare continuity between representative pads with the schematic.

The socket footprint has multiple pads with the same pin number; these are one electrical contact. Nine direct GPIO inputs mean there are no matrix diodes to fit.

## 4. Flash and fit the controller

Flash the loose RP2040-Zero before soldering it into the carrier:

1. Hold the controller's **BOOT** button while plugging its USB-C port into the Mac with a data cable.
2. Release BOOT when the removable drive **RPI-RP2** appears.
3. Copy `firmware/build/goober-rev-a-default.uf2` onto that drive. It should disappear as the module reboots into the keyboard firmware.
4. Unplug USB before soldering.

Fit the controller on the carrier's **underside, with its components and USB-C connector facing away from the carrier toward the case floor**. The USB-C end points out of the rear board edge. Use 23 header pins in two nine-pin rows and one five-pin row. Use a removable 3.0 mm gauge while soldering so the separation between the carrier underside and the controller's bare back surface is **3.0 mm**. Soldered pin strips are the intended mounting method, not stackable female sockets.

Before soldering all pins, verify with the module labels: viewed from the carrier top, GP0 is at x20.38/y1.59, and 5V is at x35.62/y1.59. Viewed from below those are mirrored. Tack opposite corners, check height and port alignment in the base, then solder the rest. Trim sharp pin ends where necessary without damaging joints.

U1's 5 V connection is supplied by its USB port. Do not connect another power source to that rail while USB is connected.

## 5. Connect and mount the OLED

Wire by **signal name**, regardless of harness color or connector order:

| Carrier J1 pad | Carrier signal | OLED terminal |
|---|---|---|
| 1, square pad | GND | GND |
| 2 | 3.3 V | VCC |
| 3 | SCL / GP15 | SCL |
| 4 | SDA / GP14 | SDA |

J1 runs from x10 to x17.62 on the carrier top drawing, with pin 1 at x10. The OLED is powered at 3.3 V. Its I²C address is 0x3C. Do not use a 5 V-powered substitute with pull-ups to 5 V.

The exact 36 × 12.5 mm Waveshare module sits in the lid's cradle with its display facing out through the window. The underside connector is toward the cradle's open end. Use thin tape on the PCB support ledges, avoiding glass and components. Dry-fit before taping: the window must show the active area, the connector must have clearance, and the module must not flex when the lid is closed.

## 6. First electrical test

Keep the assembly out of the case on an insulating surface. Use a current-limited USB test source for initial power if available. With a supply that provides power but no USB enumeration, the LEDs should remain off. Check approximately 5 V at U1's USB rail and 3.3 V at J1 VCC. If a supply immediately hits its limit or a part warms unexpectedly, disconnect and inspect the corresponding rail.

After the short checks and rail measurements pass, connect to the Mac. The Goober should enumerate as a keyboard, the OLED should show the Goober status, and lighting should start after USB configuration. If macOS opens Keyboard Setup Assistant, you can close it; this is a macro pad and has no full keyboard layout to identify.

Test one compatible switch first while supporting the socket from below. Then fit the lid/plate and the other eight switches while the base is still open. Ensure the metal switch pins are straight before pushing. Support the socket under each switch; otherwise insertion force can tear its solder pads from the PCB. The switches snap into the plate and their electrical pins engage the sockets.

## 7. Functional checklist

Use disposable text for the clipboard tests, and start with the Mac's volume low.

| Test | Expected result | Record |
|---|---|---|
| Top-left / top-middle / top-right | Command-C / Command-V / Command-Z | Pass / fail |
| Middle-left / middle / middle-right | Previous track / play-pause / next track in a compatible media app | Pass / fail |
| Bottom-left | Command-Shift-4 screenshot selection | Pass / fail |
| Bottom-middle | F13 | Pass / fail |
| Bottom-right tap | F14 | Pass / fail |
| Bottom-right hold (>200 ms) | LIGHTS layer on screen while held | Pass / fail |
| Encoder turn | Clockwise volume up, counterclockwise down; about one event per detent | Pass / fail |
| Encoder press | Mute toggle | Pass / fail |
| Hold bottom-right, turn encoder | Adjust LED brightness between 0 and 64 | Pass / fail |
| Hold bottom-right, press top-left | Toggle all key lighting | Pass / fail |
| Hold bottom-right, press top-middle/right | Next/previous lighting effect | Pass / fail |
| Hold bottom-right, middle-left / bottom-left | Hue up/down | Pass / fail |
| Hold bottom-right, middle-middle / bottom-middle | Saturation up/down | Pass / fail |
| Hold bottom-right, middle-right | Brightness up; use encoder counterclockwise for down | Pass / fail |
| Color sweep | All nine LEDs change color, in reading order; no flicker | Pass / fail |
| Several simultaneous keys | No missing keys or stuck modifiers | Pass / fail |
| Unplug / replug; reverse USB-C plug | Works both orientations and retains saved lighting settings | Pass / fail |
| Mac sleep / wake | LED rail switches off while suspended, then recovers after wake | Pass / fail |
| OLED activity | Layer and last action update; no claimed host-volume percentage | Pass / fail |
| Hot-swap replacement, power unplugged | One switch can be replaced without soldering; socket stays secure | Pass / fail |

F13/F14 may have no visible effect until assigned in macOS or an application. An event viewer or app shortcut assignment can confirm them. Volume media commands may be ignored for certain digital audio outputs; test with the Mac's built-in speakers before treating that as a PCB fault.

Measure USB current before configuration, during maximum permitted white lighting, and during suspend. Record actual readings. The descriptor requests up to 500 mA and firmware caps RGB brightness at 64/255. The power budget and suspend behavior are **not hardware certified**; the controller module's regulator and onboard LEDs also contribute. Do not raise the brightness cap until measurements justify it.

If the encoder direction is reversed on the actual part, swap `pin_a` and `pin_b` in `firmware/goober/rev_a/keyboard.json` and rebuild. If it emits two steps per detent or misses alternating detents, verify the exact encoder and its resolution setting (2 for this selected 15-pulse/30-detent part).

## 8. Close the case

Seat the PCB on the four base bosses. Tuck the OLED wires clear of screw paths and switch pins. Check the USB-C opening against the actual cable before tightening anything. Fit the lid with two **12 mm** M2.5 screws at the front key side and two **18 mm** screws at the rear control side. Tighten gently until seated; the PCB and printed spacers set the stack height.

Press the printed D-shaft knob onto the encoder without forcing it. It should retain at least a small clearance above the hood and move through the 0.5 mm push stroke without rubbing. Sand/adjust the bore from the fit of the actual shaft if needed. Add four rubber feet and repeat the controls test after closing.

To recover firmware later, unplug USB and hold the top-left key while reconnecting (QMK Bootmagic). If that does not work, open the case and use the module's physical BOOT button. The base is removable for service.

Keep a build log with part variants, print settings, measurements and any needed fit changes. Those results determine whether a revision B is needed before further production.

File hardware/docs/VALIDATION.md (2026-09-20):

# Validation record — Goober Rev A.1

Digital checks completed on 5 September 2026. This record concerns the supplied files, not a built physical device.

| Check | Result | Evidence |
|---|---|---|
| KiCad 10.0.5 schematic ERC | 0 violations | `validation/schematic-erc.json` |
| KiCad PCB DRC, all track errors | 0 violations, 0 unconnected items | `validation/pcb-final.json` |
| KiCad schematic/PCB parity | 0 issues | `validation/pcb-final.json` |
| Independent pin comparison | 141 unique connected pads, 33 functional nets agree across schematic, PCB and contract | `validation/connectivity.json` |
| Firmware/hardware GPIO map | Keys, encoder, lighting and OLED assignments agree | `validation/connectivity.json` |
| QMK build | Success for `goober/rev_a:default` | `validation/firmware-build.log` |
| UF2 format | RP2040 family, block sequence, address range and magic values verified | `validation/firmware.json` |
| Exported fabrication files | Seven Gerber layers and both drill files parse | `validation/gerber-parse.json` |
| Board geometry | 80 × 96 mm nominal; drill separation preserved; nine LED openings present | Gerbers and board drawings |
| STL base / lid / knob | Watertight, one connected body each | `validation/case-meshes.json` |
| STL coupon | Watertight, two intentional separate test pieces | `validation/case-meshes.json` |
| Nominal case intersections | No positive-volume collision with rounded PCB, controller PCB, USB connector, OLED PCB or encoder-body proxies | `validation/mechanical-clearances.json` |
| Visual review | Actual CAD assembly, exploded render, schematic, PCB and exported Gerber drawings inspected | `mockups/` |

KiCad's normal non-electrical ignored-check defaults are recorded in its report. No reported shorts, open connections, copper clearances or schematic parity errors were waived to obtain the result. The schematic uses module-style symbols; ERC is not an analog circuit simulation.

Gerbonara 1.6.3 accepted the Excellon and Gerber exports. It noted KiCad's placement of G90 after the Excellon header and an unused macro argument, plus the absence of optional paste layers when making previews. These did not prevent parsing; the fabrication ZIP intentionally contains the bare-board layers, not a solder-paste stencil order.

The mechanical intersection checks use nominal bounding proxies, not supplier STEP models for every part. They do not include solder fillets, wire bends, header tolerances, keycap travel, switch-clip forces or print shrinkage. The fit coupon and first assembled prototype must resolve those.

Still to measure physically: rail voltages and current, LED colors and timing, USB enumeration and suspend/wake, encoder direction and detent count, OLED alignment, port/cable access, switch fit and retention, screw/insert fit, solderability and sustained-use temperature. No USB/EMC compliance testing, physical prototype build or supplier DFM approval has been performed.

The AI appearance concept is illustrative. CAD/STL and PCB dimensions govern construction; the actual firmware screen is the status display described in the guide.

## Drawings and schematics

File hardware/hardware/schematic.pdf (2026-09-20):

1 | 2 | 3 | 4 | 5 | 6 | 7 | 8 | 9 | 10 | 11

A

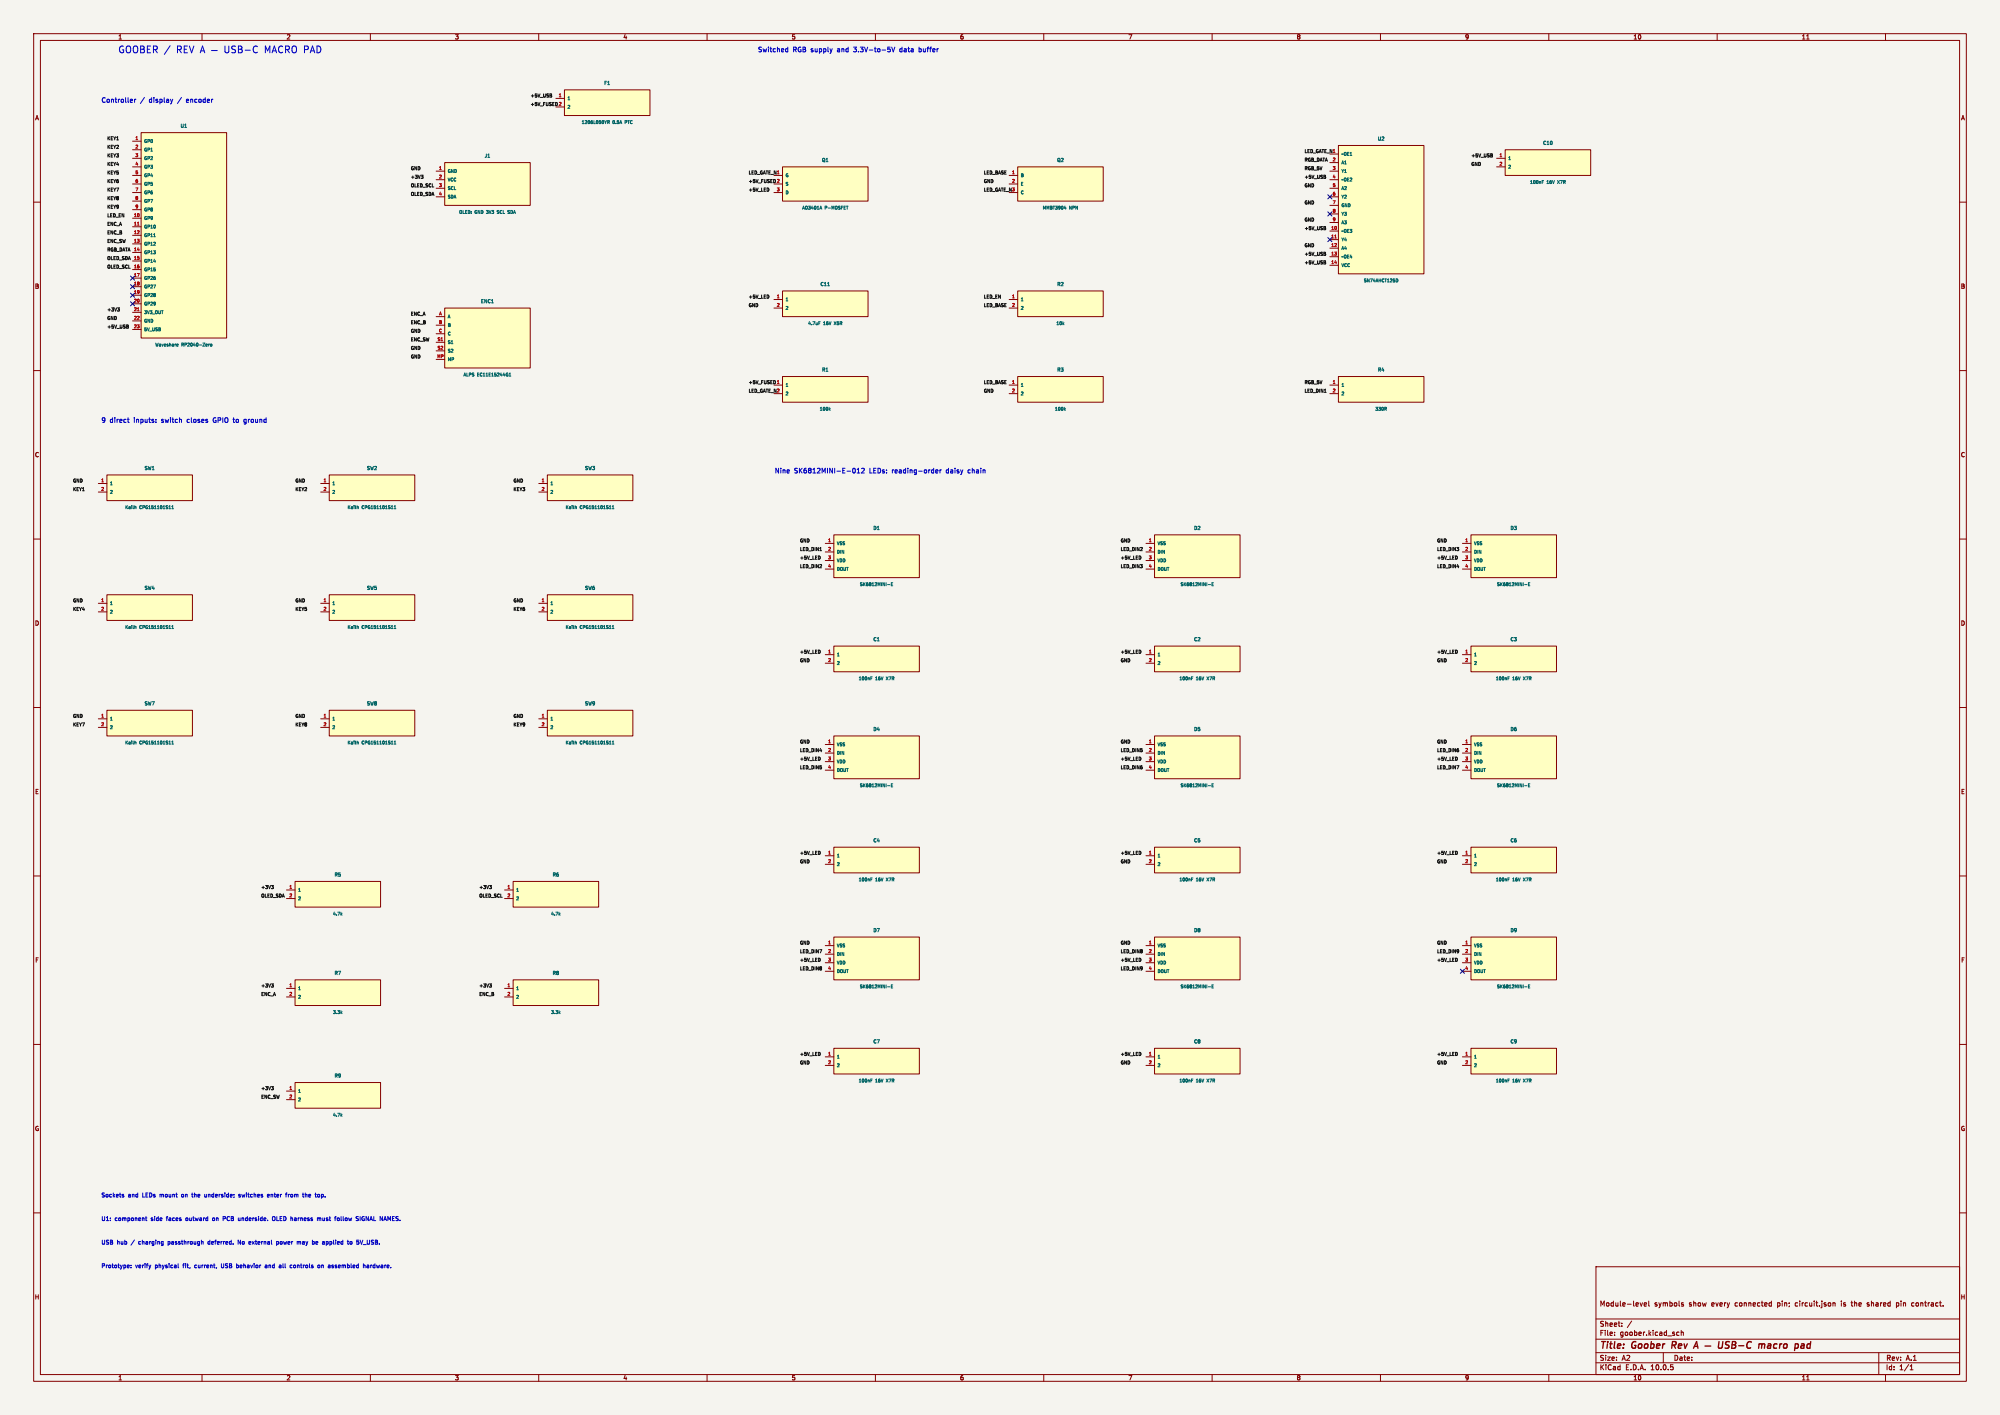
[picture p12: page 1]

GOOBER / REV A — USB-C MACRO PAD

Switched RGB supply and 3.3V-to-5V data buffer

OLED: GND 3V3 SCL SDA

9 direct inputs: switch closes GPIO to ground

Nine SK6812MINI-E-012 LEDs: reading-order daisy chain

Sockets and LEDs mount on the underside; switches enter from the top.

U1: component side faces outward on PCB underside. OLED harness must follow SIGNAL NAMES.

USB hub / charging passthrough deferred. No external power may be applied to 5V_USB.

Prototype: verify physical fit, current, USB behavior and all controls on assembled hardware.

Module-level symbols show every connected pin; circuit.json is the shared pin contract.

Sheet: /
File: goober.kicad_sch
Title: Goober Rev A — USB-C macro pad
KiCad E.D.A. 10.0.5

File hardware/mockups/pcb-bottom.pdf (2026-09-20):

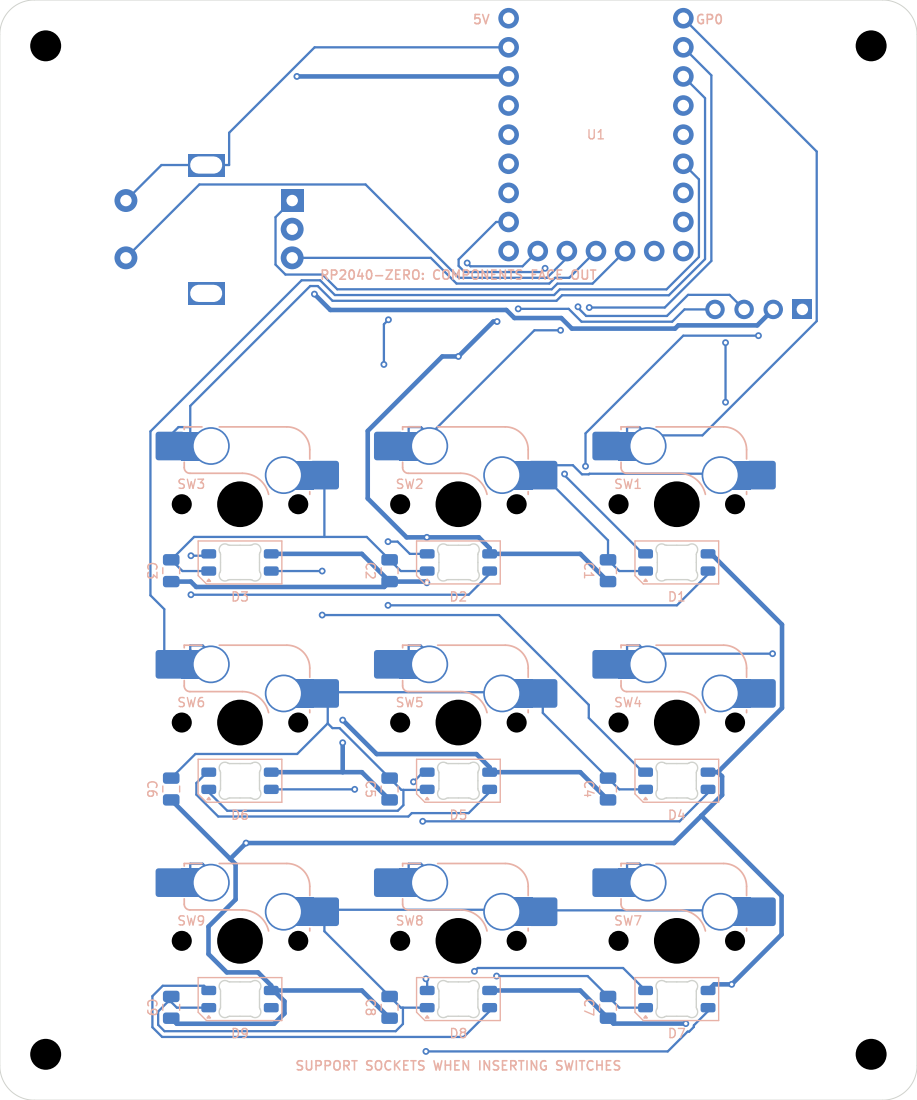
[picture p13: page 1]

RP2040-ZERO: COMPONENTS FACE OUT

SUPPORT SOCKETS WHEN INSERTING SWITCHESC4

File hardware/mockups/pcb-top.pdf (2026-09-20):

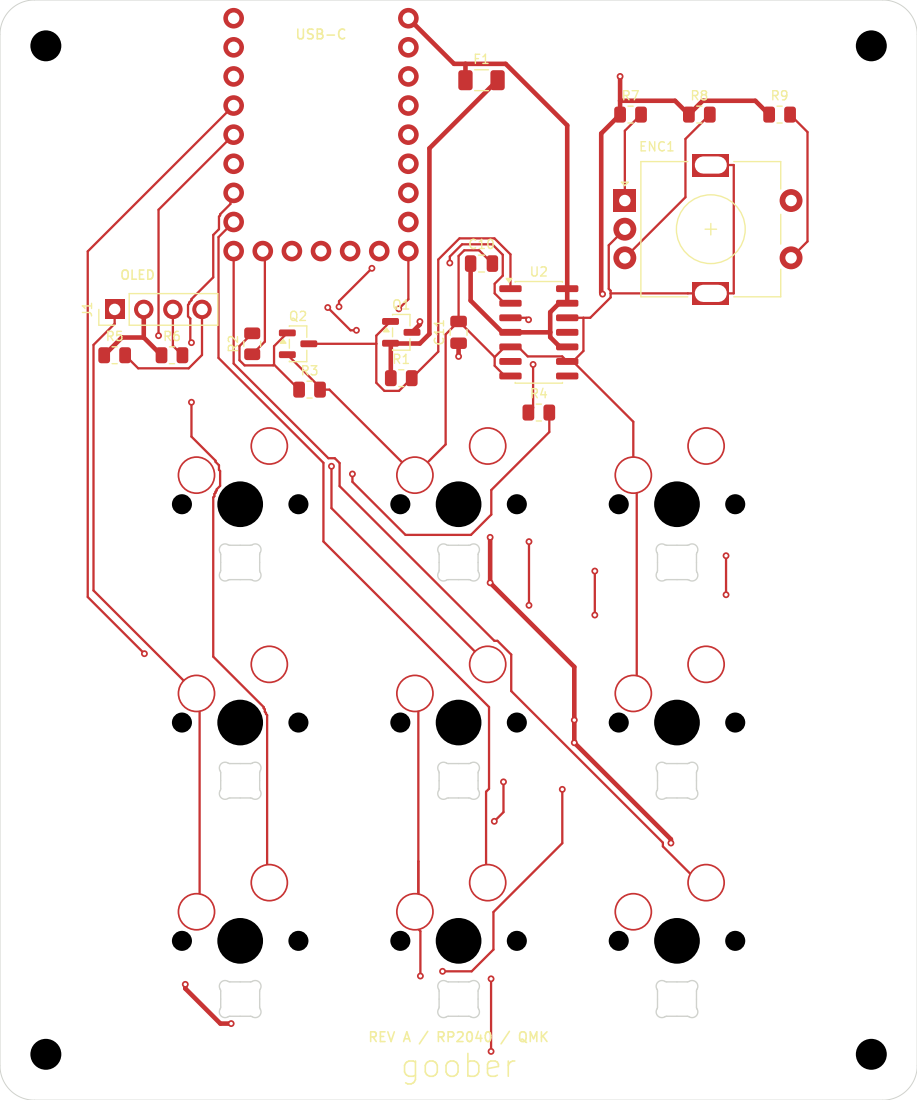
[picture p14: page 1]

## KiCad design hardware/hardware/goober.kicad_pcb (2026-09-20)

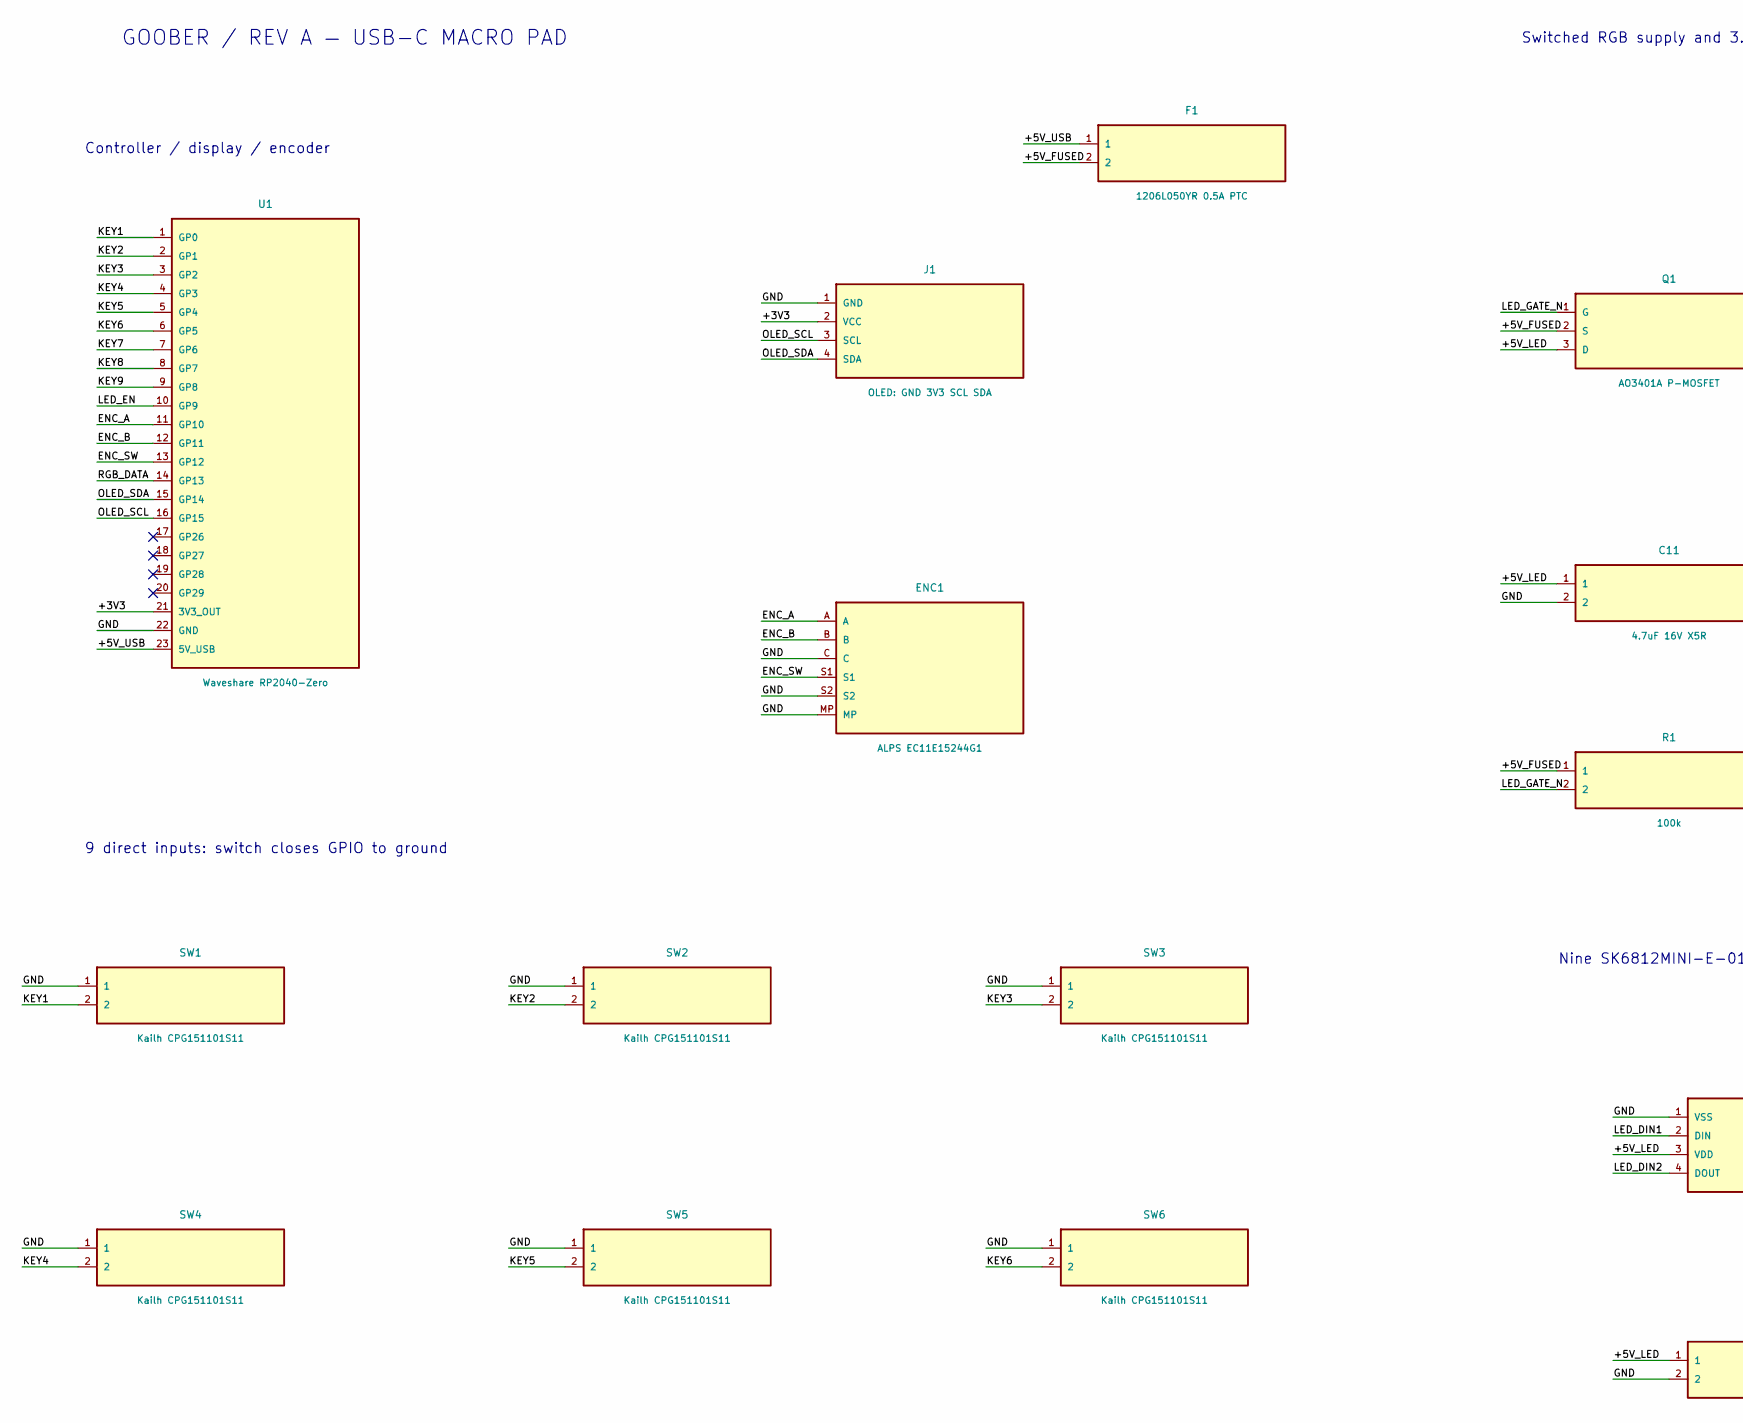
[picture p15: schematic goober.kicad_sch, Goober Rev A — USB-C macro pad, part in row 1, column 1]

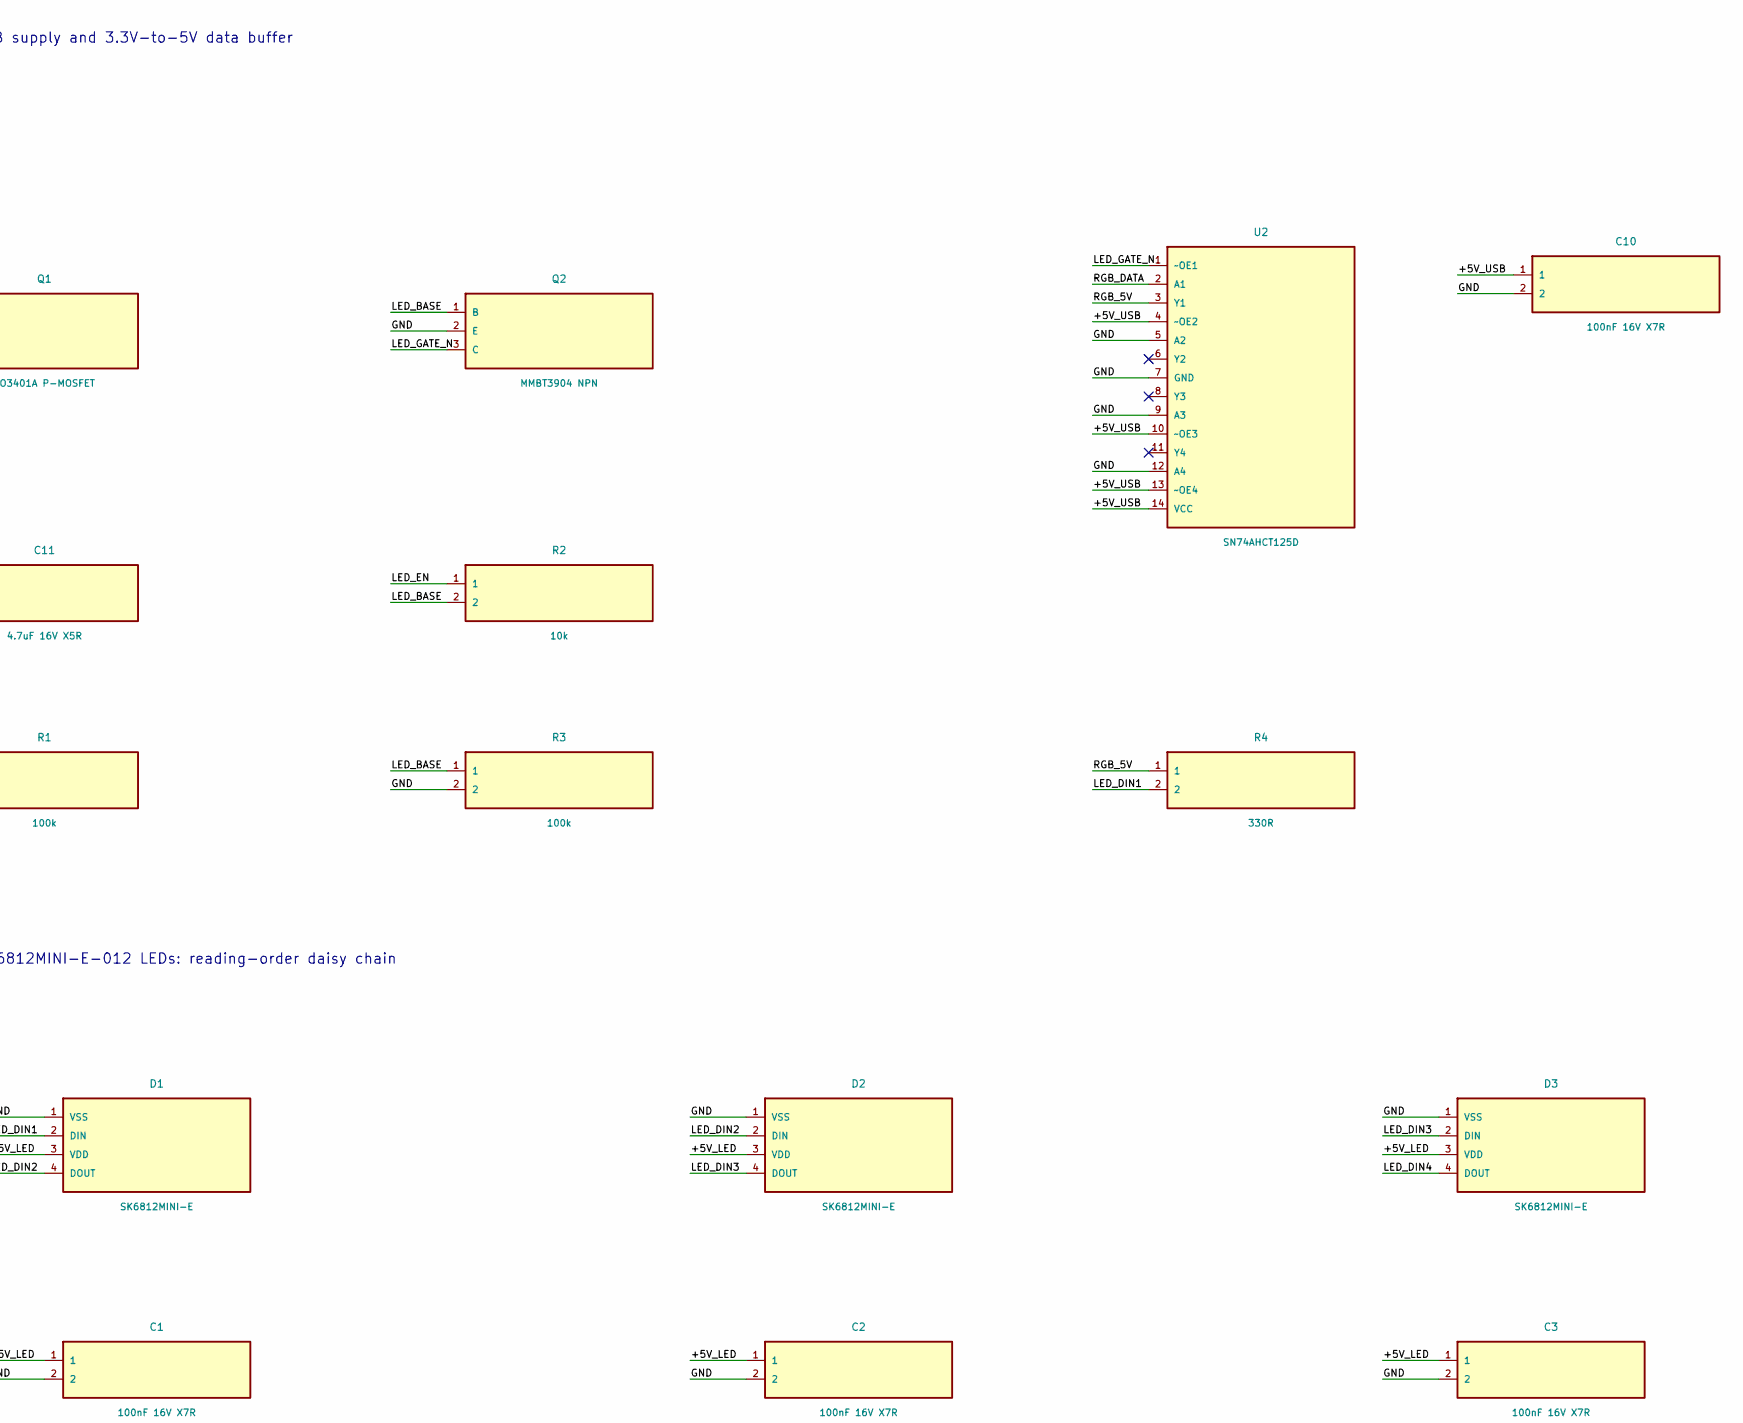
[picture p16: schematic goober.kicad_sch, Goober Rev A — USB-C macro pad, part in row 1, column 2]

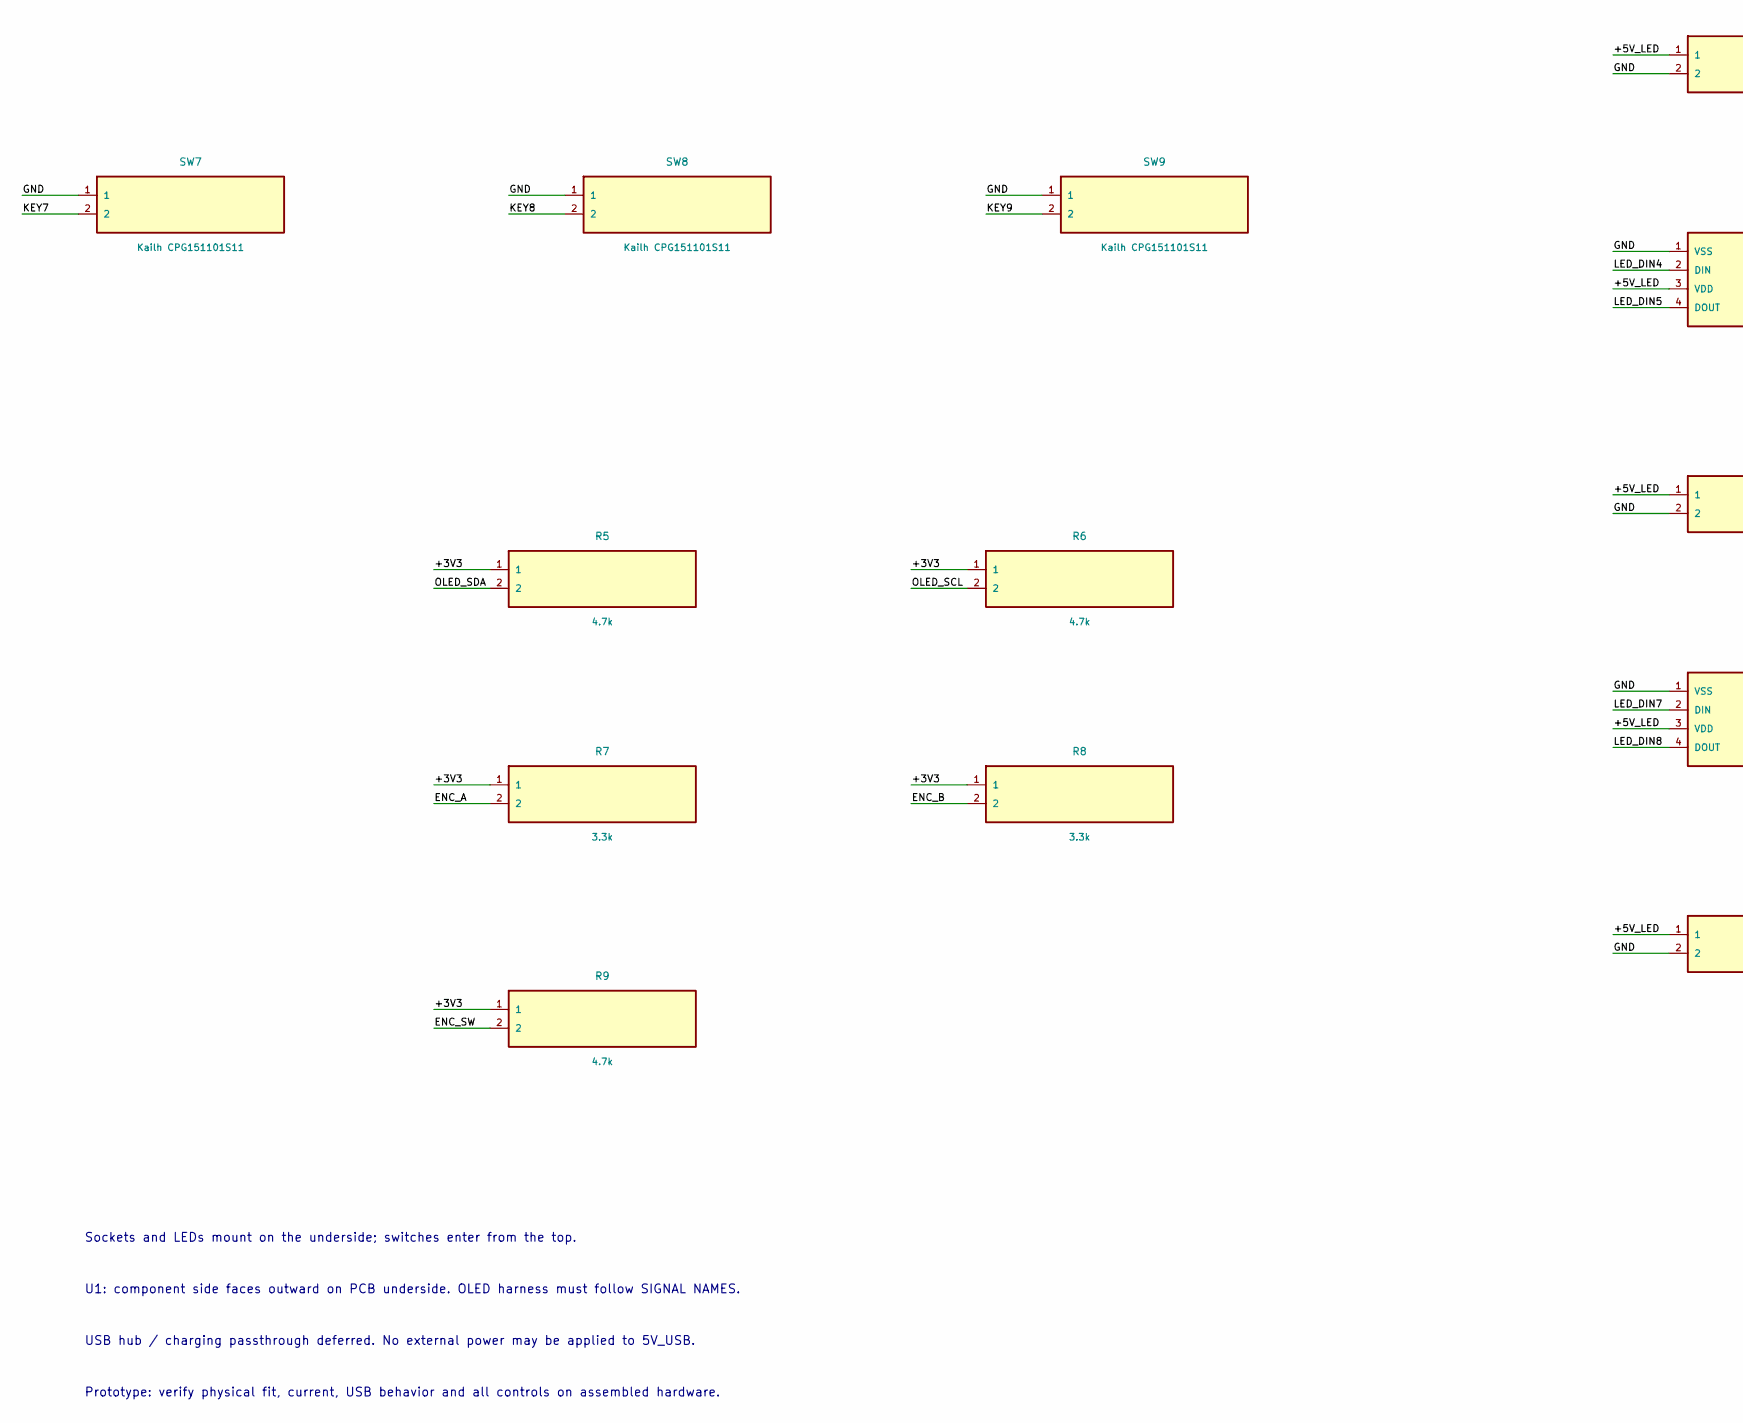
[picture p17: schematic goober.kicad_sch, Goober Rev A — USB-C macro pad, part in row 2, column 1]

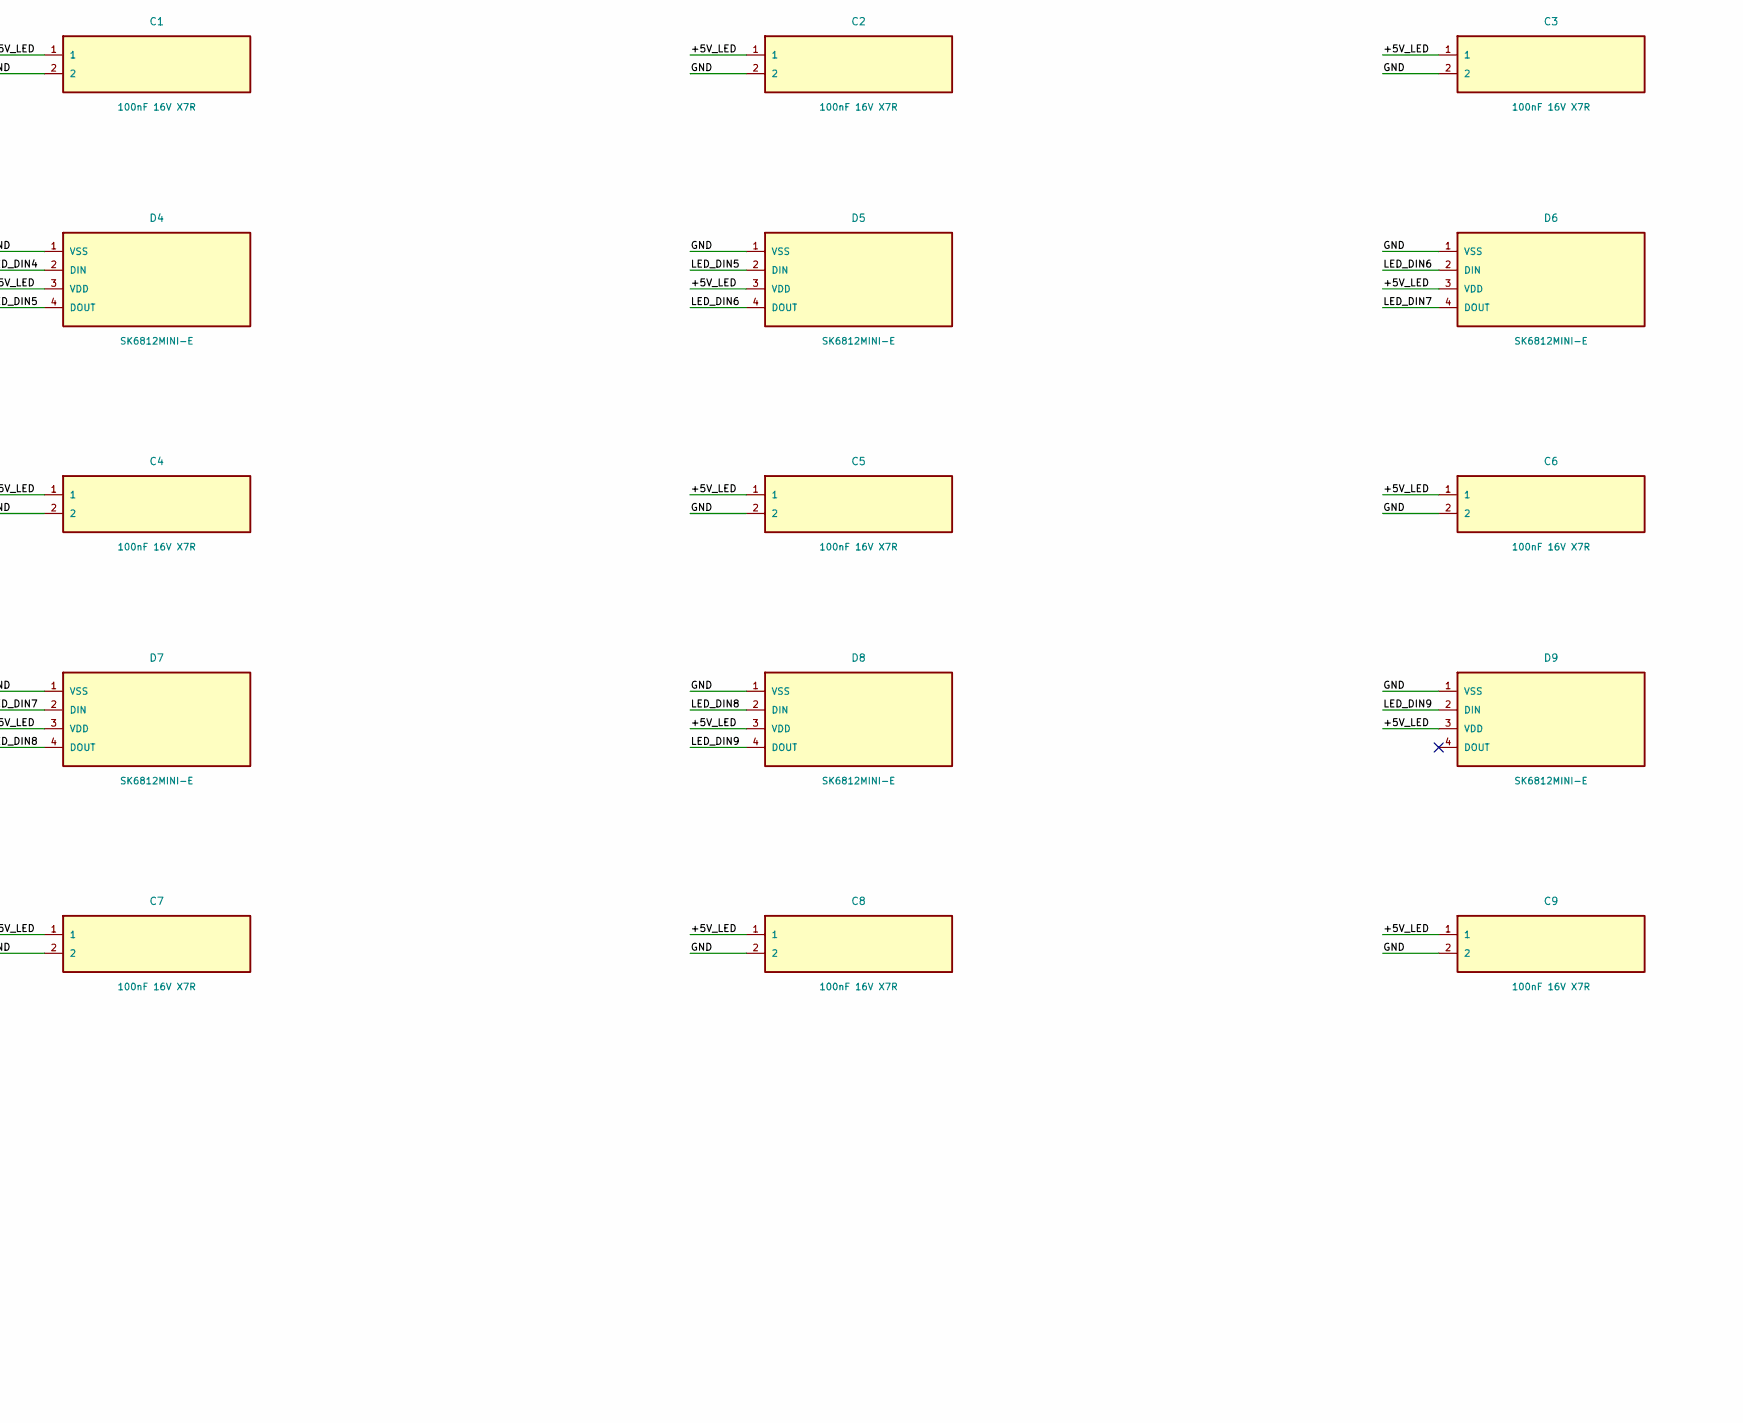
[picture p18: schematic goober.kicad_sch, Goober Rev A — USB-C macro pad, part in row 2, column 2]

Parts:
C1, C2, C3, C4, C5, C6, C7, C8, C9, C10: 100nF 16V X7R; C_0805_2012Metric
C11: 4.7uF 16V X5R; C_0805_2012Metric
D1, D2, D3, D4, D5, D6, D7, D8, D9: SK6812MINI-E; LED_SK6812MINI-E_3.2x2.8mm_P1.5mm_ReverseMount
ENC1: ALPS EC11E15244G1; RotaryEncoder_Alps_EC11E-Switch_Vertical_H20mm
F1: 1206L050YR 0.5A PTC; Fuse_1206_3216Metric
J1: OLED: GND 3V3 SCL SDA; PinHeader_1x04_P2.54mm_Vertical
Q1: AO3401A P-MOSFET; SOT-23
Q2: MMBT3904 NPN; SOT-23
R1, R3: 100k; R_0805_2012Metric
R2: 10k; R_0805_2012Metric
R4: 330R; R_0805_2012Metric
R5, R6, R9: 4.7k; R_0805_2012Metric
R7, R8: 3.3k; R_0805_2012Metric
SW1, SW2, SW3, SW4, SW5, SW6, SW7, SW8, SW9: Kailh CPG151101S11; SW_MX_HS_CPG151101S11_1u
U1: Waveshare RP2040-Zero; RP2040_Zero_Headers
U2: SN74AHCT125D; SOIC-14_3.9x8.7mm_P1.27mm

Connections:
/+3V3: J1.2 (VCC), R5.1, R6.1, R7.1, R8.1, R9.1, U1.21 (3V3_OUT)
/+5V_FUSED: F1.2, Q1.2 (S), R1.1
/+5V_LED: C1.1, C2.1, C3.1, C4.1, C5.1, C6.1, C7.1, C8.1, C9.1, C11.1, D1.3 (VDD), D2.3 (VDD), D3.3 (VDD), D4.3 (VDD), D5.3 (VDD), D6.3 (VDD), D7.3 (VDD), D8.3 (VDD), D9.3 (VDD), Q1.3 (D)
/+5V_USB: C10.1, F1.1, U1.23 (5V_USB), U2.4 (~OE2), U2.10 (~OE3), U2.13 (~OE4), U2.14 (VCC)
/ENC_A: ENC1.A, R7.2, U1.11 (GP10)
/ENC_B: ENC1.B, R8.2, U1.12 (GP11)
/ENC_SW: ENC1.S1, R9.2, U1.13 (GP12)
/GND: C1.2, C2.2, C3.2, C4.2, C5.2, C6.2, C7.2, C8.2, C9.2, C10.2, C11.2, D1.1 (VSS), D2.1 (VSS), D3.1 (VSS), D4.1 (VSS), D5.1 (VSS), D6.1 (VSS), D7.1 (VSS), D8.1 (VSS), D9.1 (VSS), ENC1.C, ENC1.MP, ENC1.S2, J1.1 (GND), Q2.2 (E), R3.2, SW1.1, SW2.1, SW3.1, SW4.1, SW5.1, SW6.1, SW7.1, SW8.1, SW9.1, U1.22 (GND), U2.5 (A2), U2.7 (GND), U2.9 (A3), U2.12 (A4)
/KEY1: SW1.2, U1.1 (GP0)
/KEY2: SW2.2, U1.2 (GP1)
/KEY3: SW3.2, U1.3 (GP2)
/KEY4: SW4.2, U1.4 (GP3)
/KEY5: SW5.2, U1.5 (GP4)
/KEY6: SW6.2, U1.6 (GP5)
/KEY7: SW7.2, U1.7 (GP6)
/KEY8: SW8.2, U1.8 (GP7)
/KEY9: SW9.2, U1.9 (GP8)
/LED_BASE: Q2.1 (B), R2.2, R3.1
/LED_DIN1: D1.2 (DIN), R4.2
/LED_DIN2: D1.4 (DOUT), D2.2 (DIN)
/LED_DIN3: D2.4 (DOUT), D3.2 (DIN)
/LED_DIN4: D3.4 (DOUT), D4.2 (DIN)
/LED_DIN5: D4.4 (DOUT), D5.2 (DIN)
/LED_DIN6: D5.4 (DOUT), D6.2 (DIN)
/LED_DIN7: D6.4 (DOUT), D7.2 (DIN)
/LED_DIN8: D7.4 (DOUT), D8.2 (DIN)
/LED_DIN9: D8.4 (DOUT), D9.2 (DIN)
/LED_EN: R2.1, U1.10 (GP9)
/LED_GATE_N: Q1.1 (G), Q2.3 (C), R1.2, U2.1 (~OE1)
/OLED_SCL: J1.3 (SCL), R6.2, U1.16 (GP15)
/OLED_SDA: J1.4 (SDA), R5.2, U1.15 (GP14)
/RGB_5V: R4.1, U2.3 (Y1)
/RGB_DATA: U1.14 (GP13), U2.2 (A1)

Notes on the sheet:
GOOBER / REV A — USB-C MACRO PAD
Controller / display / encoder
9 direct inputs: switch closes GPIO to ground
Switched RGB supply and 3.3V-to-5V data buffer
Nine SK6812MINI-E-012 LEDs: reading-order daisy chain
Sockets and LEDs mount on the underside; switches enter from the top.
U1: component side faces outward on PCB underside. OLED harness must follow SIGNAL NAMES.
USB hub / charging passthrough deferred. No external power may be applied to 5V_USB.
Prototype: verify physical fit, current, USB behavior and all controls on assembled hardware.

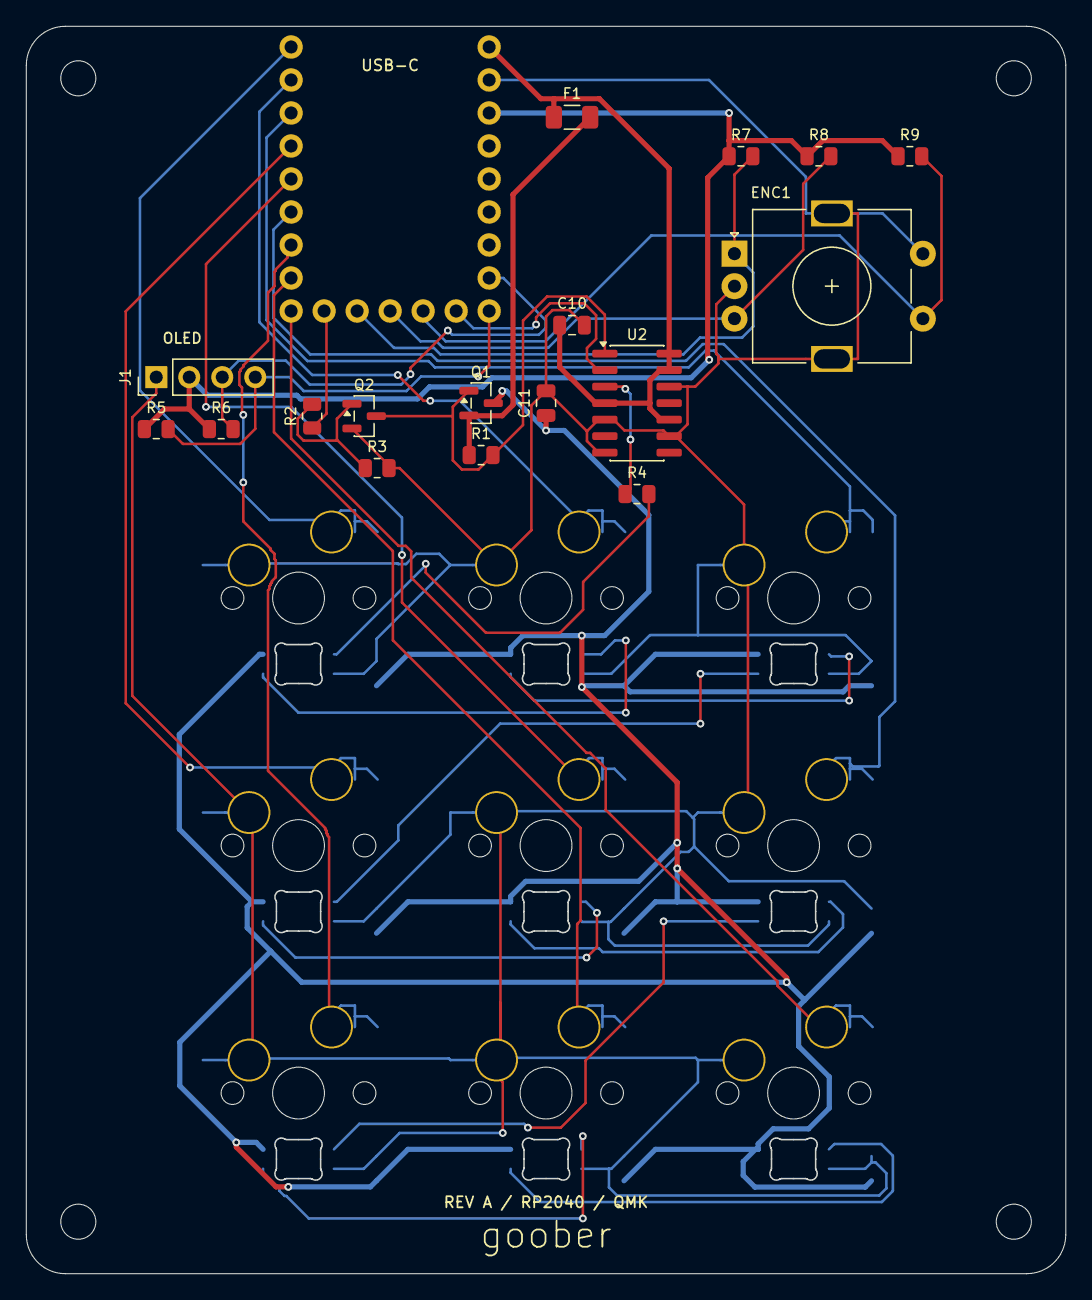
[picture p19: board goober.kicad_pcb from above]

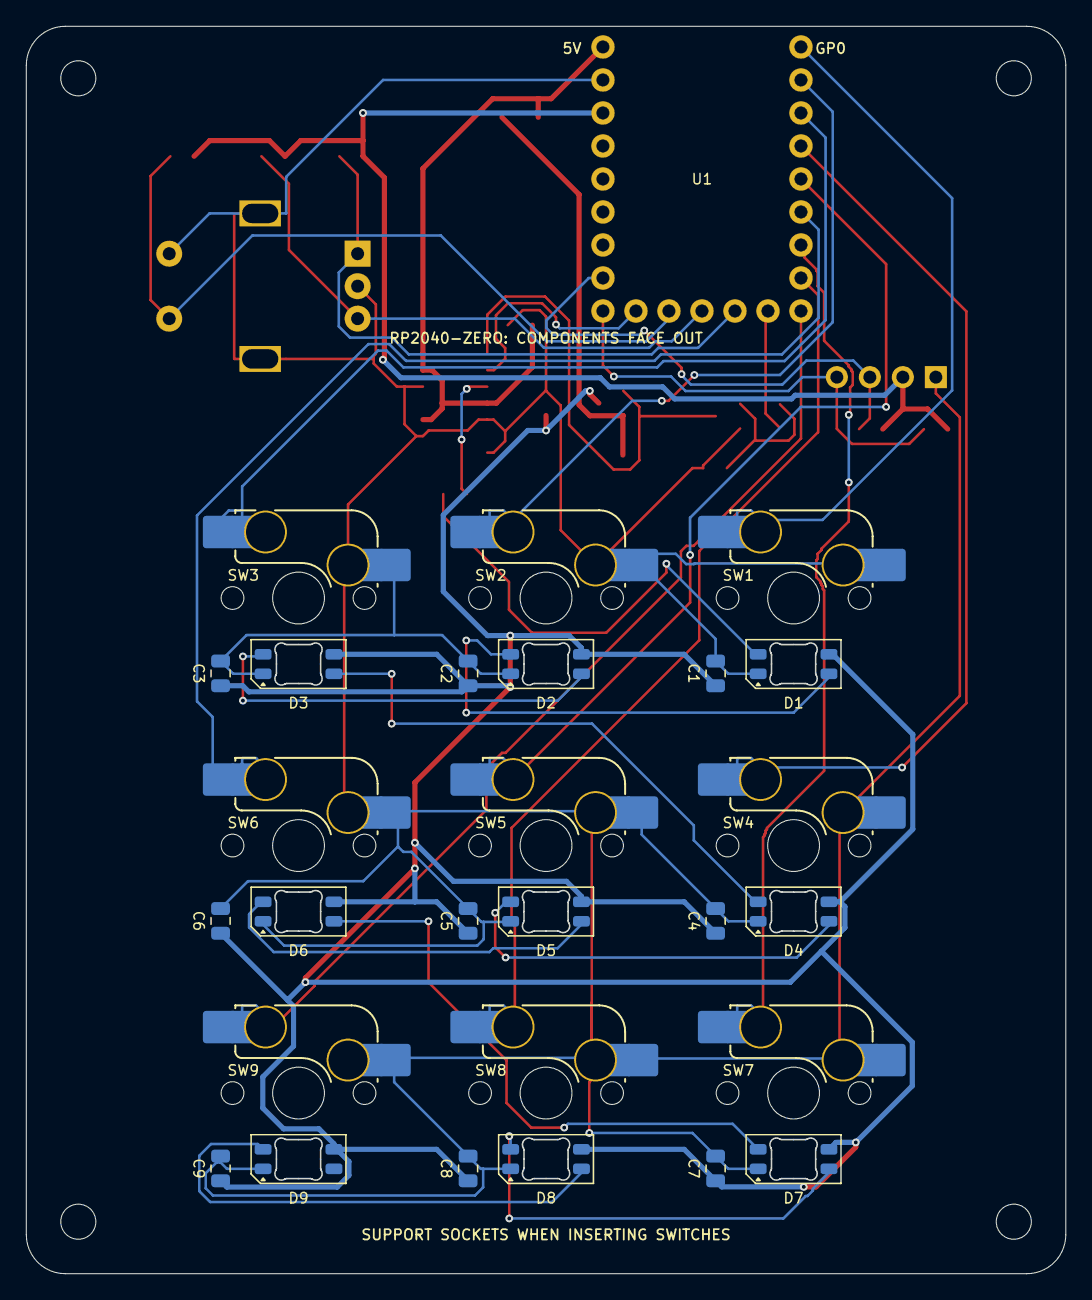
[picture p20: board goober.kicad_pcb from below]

Board: 2 copper layers, 80.0 x 96.0 mm, 49 parts (28 on the bottom side), 33 nets.

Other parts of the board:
H1, H2, H3, H4: M2.5 mounting; MountingHole_2.7mm_M2.5

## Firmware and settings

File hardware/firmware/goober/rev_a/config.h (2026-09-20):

// SPDX-License-Identifier: GPL-2.0-or-later
#pragma once
#define I2C_DRIVER I2CD1
#define I2C1_SDA_PIN GP14
#define I2C1_SCL_PIN GP15
#define I2C1_CLOCK_SPEED 400000
#define OLED_DISPLAY_128X32
#define OLED_DISPLAY_ADDRESS 0x3C
#define OLED_TIMEOUT 30000
#define RGB_MATRIX_MAXIMUM_BRIGHTNESS 64
#define RGB_MATRIX_DEFAULT_VAL 32
#define RGB_MATRIX_DEFAULT_MODE RGB_MATRIX_CYCLE_LEFT_RIGHT
#define RGB_MATRIX_SLEEP
#define RGB_MATRIX_KEYPRESSES
#define RGB_MATRIX_LED_FLUSH_LIMIT 20
#define GOOBER_LED_POWER GP9
#define TAPPING_TERM 200
#define RP2040_BOOTLOADER_DOUBLE_TAP_RESET

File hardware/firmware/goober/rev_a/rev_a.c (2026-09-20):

// SPDX-License-Identifier: GPL-2.0-or-later
#include QMK_KEYBOARD_H
#include "usb_device_state.h"

static void update_led_power(void) {
    bool on = usb_device_state_get_configure_state() == USB_DEVICE_STATE_CONFIGURED
              && rgb_matrix_is_enabled();
    gpio_write_pin(GOOBER_LED_POWER, on);
}

void keyboard_pre_init_kb(void) {
    gpio_write_pin_low(GOOBER_LED_POWER);
    gpio_set_pin_output(GOOBER_LED_POWER);
    keyboard_pre_init_user();
}

void housekeeping_task_kb(void) {
    update_led_power();
    housekeeping_task_user();
}

void notify_usb_device_state_change_kb(struct usb_device_state state) {
    update_led_power();
    notify_usb_device_state_change_user(state);
}

void suspend_power_down_kb(void) {
    gpio_write_pin_low(GOOBER_LED_POWER);
    oled_off();
    suspend_power_down_user();
}

void suspend_wakeup_init_kb(void) {
    update_led_power();
    suspend_wakeup_init_user();
}
